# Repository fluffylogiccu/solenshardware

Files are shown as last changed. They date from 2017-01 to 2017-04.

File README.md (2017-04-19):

# solenshardware
_Most definitely not hardware_

----

For current schematics (not necessarily matching last board spin!), see [Solens_Schematic.pdf](https://github.com/fluffylogiccu/solenshardware/blob/master/Altium/Solens/Project%20Outputs%20for%20Solens/Solens_Schematic.pdf)

For the current state of the board (board layers, overview, schematic, etc), see [Solens_All.pdf](https://github.com/fluffylogiccu/solenshardware/blob/master/Altium/Solens/Project%20Outputs%20for%20Solens/Solens_All.pdf)

For schematics and board files matching a particular spin, see [Releases](https://github.com/fluffylogiccu/solenshardware/releases). Each release has up-to-date Gerbers corresponding to the board files, as well as the matching BOM.

A wiki (still under development) can be found [here](https://github.com/fluffylogiccu/solenshardware/wiki). The wiki is _not_ full documentation, due to the nature of Senior Design Lab, our team's design documents are not yet public. Eventually, we hope to open-source this project.

----

## Rev. B PCB

Rev. B top

Rev. B bottom

----

## Rev. A PCB

Rev. A top

Rev. A bottom

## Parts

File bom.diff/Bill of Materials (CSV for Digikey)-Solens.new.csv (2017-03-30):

DigikeyPN | Quantity | Designator | Value | PartNumber | Comment | Footprint | Description | LibRef | Library Reference | LoadCapacitance | Model:Footprint | Pins | ScrewSize | VisibleNetName
LTC2055HMS8#PBF-ND | 1 | U302 |  | LTC2055 |  | TSOP65P490X110-8N | Dual zero-drift op amp | LTC2054/LTC2055 | LTC2054/LTC2055 |  | TSOP, 8-Leads, Body 3.00x3.00mm (LTC2054/LTC2055) | 8
638-1120-1-ND | 1 | U301 |  | EMC1412-1-ACZL-TR |  | TSOP65P490X110-8N | Dual channel I2C temperature sensor | EMC1412 | EMC1412 |  | TSOP, 8-Leads, Body 3.00x3.00mm, Pitch 0.65mm (MSOP-8, MCP79412) | 8
MCP79412-I/MS-ND | 1 | U300 |  | MCP79412 |  | TSOP65P490X110-8N | I2C RTC w/ SRAM and EEPROM | MCP7941x | MCP7941x |  | TSOP, 8-Leads, Body 3.00x3.00mm, Pitch 0.65mm (MSOP-8, MCP79412) | 8
732-7046-1-ND | 3 | SW100, SW101, SW700 |  | 434121043816 | BTN0, RESET, RESET | 4341x10438x6 | WS-TASV 6.0x3.5 mm SMD | WS-TASV, 434121043816 | WS-TASV, 434121043816 |  | 6.0*3.5mm vertical type, SMD, height 4.3mm, white actuator, 260gf, T&R | 2
LTC2943IDD#PBF-ND | 1 | U203 |  | LTC2943 |  | DFN8-3x3 | Multi-cell I2C fuel gauge | LTC2943A | LTC2943A |  | LTC2943 | 9
497-1549-1-ND | 1 | U201 |  | LM234SM | LM234SM | SOIC127P600X175-8N (LM234) | Adjustable current source | LM234 | LM234 |  | SOIC, 8-Leads, Body 4.90x3.90mm, Pitch 1.27mm, | 3
36-5016CT-ND | 5 | TP105, TP106, TP200, TP303, TP702 |  |  | TP_LARGE | TP_LARGE |  | TP_LARGE | TP_LARGE |  | 5016 | 1 |  | GND
568-5818-1-ND | 2 | Q700, Q701 |  | 2N7002 |  | SOT95P240X100-3N (CMPSH1-4 TR) | N-Channel MOSFET | MOSFET-N | MOSFET-N |  | SOT23, 3-Leads, Body 2.90x2.40mm, | 3
MMBT3904LT1GOSCT-ND | 1 | Q300 |  | MMBT3904 |  | SOT90P240X110-3N | NPN General Purpose Amplifier | 2N3904 | 2N3904 |  | SOT23, 3-Leads, Body 2.90x2.40mm, Pitch 0.90mm, MMBT3904 | 3
36-9923-ND | 4 | MTGH1, MTGH2, MTGH3, MTGH4 |  |  | MTGH | MTGH-M3x0.5-ClipSW, MTGH-M3x0.5-ClipNW, MTGH-M3x0.5-ClipNE, MTGH-M3x0.5 | Mounting hole | MTGH | MTGH |  | M3 x 0.5 pan head mounting hole, SW corner clipped, M3 x 0.5 pan head mounting hole, NW corner clipped, M3 x 0.5 pan head mounting hole, NE corner clipped, M3 x 0.5 pan head mounting hole | 1 | M3x0.5
LT8608IMSE#PBF-ND | 1 | U400 |  | LT8608 |  | TSSOP50P490X110_HS-11N | 42V 1.5A step-down, low Iq | LT8608 | LT8608 |  | TSSOP, 10-Leads, Body 3.00x3.00mm, Pitch 0.50mm, Thermal Pad 1.88x1.68mm, IPC Medium Density | 11
609-3201-ND | 1 | JP700 |  |  | 2x2 100 mil | HDR2X2 | Header, 2-Pin, Dual row | Header 2X2 | Header 2X2 |  | Connector; Header; 2x2 Position | 4
732-5316-ND | 1 | JP200 |  |  | SHDN_EN | HDR_100TH_1x3 | 3-pos Jumper | JP-3 | JP-3 |  | 100TH pin header 1x3 vertical | 3
609-3264-ND | 1 | J700 |  |  | HDR_FTDI_EXTENDED | HDR1X8 |  | HDR_FTDI_EXTENDED | HDR_FTDI_EXTENDED |  | Connector; Header; 8 Position | 8
LT3652HVIMSE#PBF-ND | 1 | U200 |  | LT3652 |  | TSOP65P490X110_HS-13N (LT3652) | MPPC and battery charger | LT3652 | LT3652 |  | TSOP, 12-Leads, Body 4.04x3.00mm, Pitch 0.65mm, Thermal Pad 2.95x1.76mm, | 13
497-14053-ND | 1 | U100 |  | STM32F429 | STM32F429 | TSQFP50P2200X2200X160-144M | Cortex-M4 microcontroller | STM32F429 | STM32F429 |  | TSQFP, 144-Leads, Body 20.00x20.00mm, Pitch 0.50mm, STM32F429 | 144
609-3221-ND | 1 | J600 |  |  | CAMERA_2x10 | OV5642_HDR_2x10 | 20-pin parallel camera connector for OV5642 | CAMERA_2x10 | CAMERA_2x10 |  | OV5642 camera 100TH pin header 2x10 vertical | 20
732-5317-ND | 1 | J400 |  |  | EXT 3V3 | HDR1X4 | Header, 4-Pin | Header 4 | Header 4 |  | Connector; Header; 4 Position | 4
732-2772-ND | 1 | J200 |  | 691322110005 | 691322110005 | 691322110005 | WR-TBL Terminal block - serie 3221 - 3.50 mm | 691322110005 | 691322110005 |  | 3,50mm - PCB Horizontal - 05p | 5
36-5015CT-ND | 19 | TP100, TP101, TP104, TP203, TP204, TP205, TP207, TP208, TP209, TP300, TP301, TP302, TP304, TP305, TP306, TP600, TP601, TP700, TP701 |  |  |  | TP_SMALL |  | TP_SMALL | TP_SMALL |  | 5015 | 1 |  | TX, RX, 3V3, VBAT_INT, VINFB, VFB, VBAT, CHRG, FAULT, SDA, SCL, ALERT, SPECT0, SPECT1, LED0, SDA, SCL, TX, RX
WM17452-ND | 2 | J103, J701 |  |  | HDR_SWD_2x6, ESP_GPIO | HDR_100TH_2X6_SMT | 6 pin SWD connector with +6 GND pins, Header, 6-Pin, Dual row | HDR_SWD_2x6, Header 6X2 | HDR_SWD_2x6, Header 6X2 |  | 100TH pin header, 2x6, SMT | 12
WM17454-ND | 1 | J102 |  |  | GPIO | HDR_100TH_2X8_SMT | Header, 8-Pin, Dual row | Header 8X2 | Header 8X2 |  | 100TH pin header, 2x8, SMT | 16
 | 21 | J101, R106, R107, R108, R205, SJ100, SJ101, SJ102, SJ106, SJ107, SJ108, SJ109, SJ112, SJ200, SJ201, SJ300, SJ301, SJ700, TP500, TP501, U700 |  |  | 2x2 100 mil SMT, 0805, 0805, 0805, 0805, 0805, 0805, 0805, 0805, 0805, 0805, 0805, 0805, SJ, SJ, 0805, 0805, 1206, TP_TINY, TP_TINY, [NoValue] | HDR_100TH_2X2_SMT, RES_0805, RES_0805, RES_0805, RES_0805, SJ_0805, SJ_0805, SJ_0805, SJ_0805, SJ_0805, SJ_0805, SJ_0805, SJ_0805, SJ_0805, SJ_0805, SJ_0805, SJ_0805, SJ_1206, TP_TINY, TP_TINY, ESP8266 ESP-12-E | Header, 2-Pin, Dual row, Resistor, Resistor, Resistor, Resistor, Solder jumper, Solder jumper, Solder jumper, Solder jumper, Solder jumper, Solder jumper, Solder jumper, Solder jumper, Solder jumper, Solder jumper, Solder jumper, Solder jumper, Solder jumper, [NoValue], [NoValue], ESP8266 ESP-12-E | Header 2X2, Res1, Res1, Res1, Res1, SJ, SJ, SJ, SJ, SJ, SJ, SJ, SJ, SJ, SJ, SJ, SJ, SJ, TP_TINY, TP_TINY, ESP8266 ESP-12-E | Header 2X2, Res1, Res1, Res1, Res1, SJ, SJ, SJ, SJ, SJ, SJ, SJ, SJ, SJ, SJ, SJ, SJ, SJ, TP_TINY, TP_TINY, ESP8266 ESP-12-E |  | 100TH pin header, 2x2, SMT, [NoValue], [NoValue], [NoValue], [NoValue], [NoValue], [NoValue], [NoValue], [NoValue], [NoValue], [NoValue], [NoValue], [NoValue], [NoValue], [NoValue], [NoValue], [NoValue], A big fat solder jumper for high-current, 1mm round tiny testpoint, 1mm round tiny testpoint, ESP8266 ESP-12-E |  |  | [NoParam], [NoParam], [NoParam], [NoParam], [NoParam], [NoParam], [NoParam], [NoParam], [NoParam], [NoParam], [NoParam], [NoParam], [NoParam], [NoParam], [NoParam], [NoParam], [NoParam], [NoParam], GND, CLK, [NoParam]
609-3263-ND | 1 | J100 |  |  | HDR_FTDI | HDR_100TH_1x6 | Sparkfun FTDI pinout connector | HDR_FTDI | HDR_FTDI |  | 100TH pin header 1x6 vertical | 6
732-4978-1-ND | 3 | D301, D305, D400 |  |  | 0603, 0603, 3V3 | LED_0603 | Typical INFRARED GaAs LED, Typical INFRARED GaAs LED, [NoValue] | LED0 | LED0 |  |  | 2
732-4971-1-ND | 3 | D203, D204, D300 |  |  | CHRG, FAULT, 0603 | LED_0603 | [NoValue], [NoValue], Typical INFRARED GaAs LED | LED0 | LED0 |  |  | 2
CMPSH1-4 CT-ND | 1 | D202 |  | CMPSH1-4 |  | SOT95P240X100-3N (CMPSH1-4 TR) | Schottky Diode | D Schottky | D Schottky |  | SOT23, 3-Leads, Body 2.90x2.40mm, | 2
CMSH3-40MA TR13CT-ND | 2 | D200, D201 |  | CMSH3-40MA |  | SODFL519X262-2N (CMSH3-40MA) | Schottky Diode | D Schottky | D Schottky |  | SODFL, 2-Leads, Body 2.60x5.19mm, | 2
706-1132-ND | 1 | U500 |  | IS42S16400J |  | TSOP80P1170X120-54N | 1Mb x 16 x 4 bank (64 Mbit) SDRAM | IS42S16400J | IS42S16400J |  | TSOP, 54-Leads, Body 22.22x10.16mm, (IS42S16400J) | 54
36-5106CT-ND | 1 | R400 | 0 |  | 1206 | RES_1206 | Resistor | Res1 | Res1 |  |  | 2
311-1.00MLRCT-ND | 2 | R303, R308 | 1M |  | 0402 | RES_0402 | Resistor | Res1 | Res1 |  |  | 2
311-1.00MCRCT-ND | 1 | R401 | 1M |  | 0805 | RES_0805 | Resistor | Res1 | Res1 |  |  | 2
311-1.00KCRCT-ND | 1 | R208 | 1k |  | 0805 | RES_0805 | Resistor | Res1 | Res1 |  |  | 2
1276-1020-1-ND | 1 | C700 | 1n |  | 0805 | CAP_0805 | Capacitor | Cap | Cap |  |  | 2
1276-6470-1-ND | 2 | C200, C207 | 1u |  | 0805,50V, 0805 | CAP_0805 | Capacitor | Cap | Cap |  |  | 2
587-2098-1-ND | 1 | L400 | 2.2u | NR6028T2R2N |  | IND_TAIYO_NR6028 | Inductor | Inductor | Inductor |  |  | 2
1276-6458-1-ND | 4 | C113, C114, C115, C407 | 2.2u |  | 0805 | CAP_0805 | Capacitor | Cap | Cap |  |  | 2
311-3.30KCRCT-ND | 5 | R300, R301, R302, R600, R601 | 3.3k |  | 0805 | RES_0805 | Resistor | Res1 | Res1 |  |  | 2
1276-3343-1-ND | 3 | C201, C202, C203 | 4.7u |  | 1210,50V | CAP_1210 | Capacitor | Cap | Cap |  |  | 2
887-1263-1-ND | 1 | Y100 | 8M000 | 9C-8.000MEEJ-T |  | HC-49S | Crystal Oscillator | XTAL | XTAL | 18p | Crystal | 2
311-10.0KCRCT-ND | 7 | R700, R701, R702, R703, R706, R708, R711 | 10k |  | 0805 | RES_0805 | Resistor | Res1 | Res1 |  |  | 2
3361P-103GLFCT-ND | 1 | VR200 | 10k |  | Vin Set | RES_3361P |  | TrimPot | TrimPot |  | POT | 3
1276-1015-1-ND | 1 | C408 | 10n |  | 0805 | CAP_0805 | Capacitor | Cap | Cap |  |  | 2
1276-1109-1-ND | 1 | C403 | 10p |  | 0805 | CAP_0805 | Capacitor | Cap | Cap |  |  | 2
1276-6455-1-ND | 2 | C404, C406 | 10u |  | 0805 | CAP_0805 | Capacitor | Cap | Cap |  |  | 2
1276-1312-1-ND | 5 | C205, C206, C401, C601, C702 | 10u |  | 1206,16V, 1206,16V, 1206,16V, 1206,16V, 1206 | CAP_1206 | Capacitor | Cap | Cap |  |  | 2
587-2973-1-ND | 1 | L200 | 15u | NRS8040T150MJGJ |  | IND_TAIYO_NRS804 | Inductor | Inductor | Inductor |  |  | 2
490-6203-1-ND | 4 | C102, C103, C300, C301 | 18p |  | 0402 | CAP_0402 | Capacitor | Cap | Cap |  |  | 2
311-20.5KCRCT-ND | 1 | R405 | 20.5k |  | 0805 | RES_0805 | Resistor | Res1 | Res1 |  |  | 2
311-22.0KCRCT-ND | 4 | R201, R202, R204, R206 | 22k |  | 0805 | RES_0805 | Resistor | Res1 | Res1 |  |  | 2
CSR1206FK25L0CT-ND | 1 | R210 | 25m |  | 1206 | RES_1206 | Resistor | Res1 | Res1 |  |  | 2
1276-1153-1-ND | 2 | C100, C101 | 27p |  | 0402 | CAP_0402 | Capacitor | Cap | Cap |  |  | 2
535-9166-1-ND | 2 | Y101, Y300 | 32K768 | ABS25-32.768KHZ-T |  | XTAL-SOJ-4 |  | XTAL-SOJ-4 | XTAL-SOJ-4 | 12.5p |  | 4
CRA6S833CT-ND | 7 | RR503, RR504, RR505, RR506, RR600, RR601, RR602 | 33 |  | RES_ARR_4 | CAC-80P319X150-8M | 4 element resistor array | RES_ARR_4 | RES_ARR_4 |  | Chip Array, ConvexS, 8-Leads, Pitch 0.80mm, Body 3.20x1.50mm, for Vishay CRA06S | 8
1276-3063-1-ND | 3 | C405, C600, C701 | 47u |  | 1206,10V | CAP_1206 | Capacitor | Cap | Cap |  |  | 2
CRA6S849.9ACT-ND | 5 | RR500, RR501, RR502, RR507, RR508 | 49.9 |  | RES_ARR_4 | CAC-80P319X150-8M | 4 element resistor array | RES_ARR_4 | RES_ARR_4 |  | Chip Array, ConvexS, 8-Leads, Pitch 0.80mm, Body 3.20x1.50mm, for Vishay CRA06S | 8
311-49.9CRCT-ND | 5 | R110, R500, R501, R502, R602 | 49.9 |  | 0805 | RES_0805 | Resistor | Res1 | Res1 |  |  | 2
WSLC-.08CT-ND | 1 | R200 | 80m |  | 1206 | RES_1206 | Resistor | Res1 | Res1 |  |  | 2
311-100CRCT-ND | 10 | R101, R102, R104, R105, R704, R705, R707, R709, R710, R712 | 100 |  | 0805 | RES_0805 | Resistor | Res1 | Res1 |  |  | 2
311-100KCRCT-ND | 1 | R402 | 100k |  | 0805 | RES_0805 | Resistor | Res1 | Res1 |  |  | 2
587-3498-1-ND | 30 | C104, C105, C106, C107, C108, C109, C110, C111, C112, C116, C117, C118, C119, C120, C121, C122, C124, C204, C302, C303, C400, C402, C500, C501, C502, C503, C504, C505, C506, C507 | 100n |  | 0402 | CAP_0402 | Capacitor | Cap | Cap |  |  | 2
311-0.0ARCT-ND | 1 | R103 | 220 |  | 0805 | RES_0805 | Resistor | Res1 | Res1 |  |  | 2
490-1293-1-ND | 2 | C304, C305 | 220p |  | 0402 | CAP_0402 | Capacitor | Cap | Cap |  |  | 2
311-309KCRCT-ND | 1 | R404 | 309k |  | 0805 | RES_0805 | Resistor | Res1 | Res1 |  |  | 2
311-330CRCT-ND | 2 | R304, R406 | 330 |  | 0805 | RES_0805 | Resistor | Res1 | Res1 |  |  | 2
311-487KCRCT-ND | 1 | R207 | 487k |  | 0805 | RES_0805 | Resistor | Res1 | Res1 |  |  | 2
311-510CRCT-ND | 1 | R109 | 510 |  | 0805 | RES_0805 | Resistor | Res1 | Res1 |  |  | 2
311-511KCRCT-ND | 1 | R203 | 511k |  | 0805 | RES_0805 | Resistor | Res1 | Res1 |  |  | 2

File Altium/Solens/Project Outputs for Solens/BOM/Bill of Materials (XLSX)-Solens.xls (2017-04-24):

Item # | Designator | Value | Footprint | Comment | LibRef | Quantity | #Column Name Error:PackageName | PartNumber | #Column Name Error:PartType | Pins | Model:Footprint
1 | R106 | 0R | RES_0805 | 0R, 1/8W, 0805 (DNP) | Res1 | 1 |  |  |  | 2
2 | R400 | 0R 1/2W | RES_1206 | 0R, 1/2W, 1206 | Res1 | 1 |  |  |  | 2
3 | R208 | 1k | RES_0805 | 1k, 1/8W, 0805 | Res1 | 1 |  |  |  | 2
4 | R303 | 1M | RES_0402 | 1M, 1/16W, 0402 (DNP) | Res1 | 1 |  |  |  | 2
5 | R308 | 1M | RES_0402 | 1M, 1/16W, 0402 (DNP) | Res1 | 1 |  |  |  | 2
6 | R401 | 1M | RES_0805 | 1M, 1/8W, 0805 | Res1 | 1 |  |  |  | 2
7 | C700 | 1n, 10V | CAP_0805 | 1n, 16V, 0805 | Cap | 1 |  |  |  | 2
8 | C200 | 1u, 35V | CAP_0805 | 1u, 35V, 0805 | Cap | 1 |  |  |  | 2
9 | C207 | 1u, 35V | CAP_0805 | 1u, 35V, 0805 (DNP) | Cap | 1 |  |  |  | 2
10 | R205 | 2k4 | RES_0805 | 2k4, 1/8W, 0805 (DNP) | Res1 | 1 |  |  |  | 2
11 | Q700 | 2N7002 | SOT95P240X100-3N (CMPSH1-4 TR) | 2N7002, SOT-23 | MOSFET-N | 1 |  | 2N7002 |  | 3 | SOT23, 3-Leads, Body 2.90x2.40mm,
12 | Q701 | 2N7002 | SOT95P240X100-3N (CMPSH1-4 TR) | 2N7002, SOT-23 | MOSFET-N | 1 |  | 2N7002 |  | 3 | SOT23, 3-Leads, Body 2.90x2.40mm,
13 | C113 | 2u2, 10V | CAP_0805 | 2u2, 10V, 0805 | Cap | 1 |  |  |  | 2
14 | C114 | 2u2, 10V | CAP_0805 | 2u2, 10V, 0805 | Cap | 1 |  |  |  | 2
15 | C115 | 2u2, 10V | CAP_0805 | 2u2, 10V, 0805 | Cap | 1 |  |  |  | 2
16 | C407 | 2u2, 10V | CAP_0805 | 2u2, 10V, 0805 | Cap | 1 |  |  |  | 2
17 | L400 | 2.2u | IND_TAIYO_NR6028 | NR6028T2R2N | Inductor | 1 |  | NR6028T2R2N |  | 2
18 | R300 | 3k3 | RES_0805 | 3k3, 1/8W, 0805 (DNP) | Res1 | 1 |  |  |  | 2
19 | R301 | 3k3 | RES_0805 | 3k3, 1/8W, 0805 (DNP) | Res1 | 1 |  |  |  | 2
20 | R302 | 3k3 | RES_0805 | 3k3, 1/8W, 0805 (DNP) | Res1 | 1 |  |  |  | 2
21 | R600 | 3k3 | RES_0805 | 3k3, 1/8W, 0805 | Res1 | 1 |  |  |  | 2
22 | R601 | 3k3 | RES_0805 | 3k3, 1/8W, 0805 | Res1 | 1 |  |  |  | 2
23 | C201 | 4u7, 50V | CAP_1210 | 4u7, 50V, 1210 | Cap | 1 |  |  |  | 2
24 | C202 | 4u7, 50V | CAP_1210 | 4u7, 50V, 1210 | Cap | 1 |  |  |  | 2
25 | C203 | 4u7, 50V | CAP_1210 | 4u7, 50V, 1210 | Cap | 1 |  |  |  | 2
26 | Y100 | 8M000 | HC-49S | 9C-8.000MEEJ-T | XTAL | 1 |  | 9C-8.000MEEJ-T |  | 2 | Crystal
27 | R700 | 10k | RES_0805 | 10k, 1/8W, 0805 | Res1 | 1 |  |  |  | 2
28 | R701 | 10k | RES_0805 | 10k, 1/8W, 0805 | Res1 | 1 |  |  |  | 2
29 | R702 | 10k | RES_0805 | 10k, 1/8W, 0805 | Res1 | 1 |  |  |  | 2
30 | R703 | 10k | RES_0805 | 10k, 1/8W, 0805 | Res1 | 1 |  |  |  | 2
31 | R706 | 10k | RES_0805 | 10k, 1/8W, 0805 | Res1 | 1 |  |  |  | 2
32 | R708 | 10k | RES_0805 | 10k, 1/8W, 0805 | Res1 | 1 |  |  |  | 2
33 | R711 | 10k | RES_0805 | 10k, 1/8W, 0805 | Res1 | 1 |  |  |  | 2
34 | VR200 | 10k LIN | RES_3361P | 3361P-1-103GLF | TrimPot | 1 |  | 3361P-1-103GLF |  | 3 | POT
35 | C408 | 10n, 16V | CAP_0805 | 10n, 16V, 0805 | Cap | 1 |  |  |  | 2
36 | C403 | 10p, 16V | CAP_0805 | 10p, 16V, 0805 | Cap | 1 |  |  |  | 2
37 | C404 | 10u, 10V | CAP_0805 | 10u, 10V, 0805 | Cap | 1 |  |  |  | 2
38 | C406 | 10u, 10V | CAP_0805 | 10u, 10V, 0805 | Cap | 1 |  |  |  | 2
39 | C601 | 10u, 10V | CAP_1206 | 10u, 10V, 1206 | Cap | 1 |  |  |  | 2
40 | C702 | 10u, 10V | CAP_1206 | 10u, 10V, 1206 | Cap | 1 |  |  |  | 2
41 | C205 | 10u, 16V | CAP_1206 | 10u, 16V, 1206 | Cap | 1 |  |  |  | 2
42 | C206 | 10u, 16V | CAP_1206 | 10u, 16V, 1206 | Cap | 1 |  |  |  | 2
43 | C401 | 10u, 16V | CAP_1206 | 10u, 16V, 1206 | Cap | 1 |  |  |  | 2
44 | L200 | 15u | IND_TAIYO_NRS804 | NRS8040T150MJGJ | Inductor | 1 |  | NRS8040T150MJGJ |  | 2
45 | C102 | 18p, 16V | CAP_0402 | 18p, 16V, 0402 | Cap | 1 |  |  |  | 2
46 | C103 | 18p, 16V | CAP_0402 | 18p, 16V, 0402 | Cap | 1 |  |  |  | 2
47 | C300 | 18p, 16V | CAP_0402 | 18p, 16V, 0402 (DNP) | Cap | 1 |  |  |  | 2
48 | C301 | 18p, 16V | CAP_0402 | 18p, 16V, 0402 (DNP) | Cap | 1 |  |  |  | 2
49 | R405 | 20k5 | RES_0805 | 20k5, 1/8W, 0805 | Res1 | 1 |  |  |  | 2
50 | R201 | 22k | RES_0805 | 22k, 1/8W, 0805 | Res1 | 1 |  |  |  | 2
51 | R202 | 22k | RES_0805 | 22k, 1/8W, 0805 | Res1 | 1 |  |  |  | 2
52 | R204 | 22k | RES_0805 | 22k, 1/8W, 0805 | Res1 | 1 |  |  |  | 2
53 | R206 | 22k | RES_0805 | 22k, 1/8W, 0805 | Res1 | 1 |  |  |  | 2
54 | R210 | 25m, 1%, 1/2W | RES_1206 | 25m, 1/2W, 1%, 1206 | Res1 | 1 |  |  |  | 2
55 | C100 | 27p, 16V | CAP_0402 | 27p, 16V, 0402 | Cap | 1 |  |  |  | 2
56 | C101 | 27p, 16V | CAP_0402 | 27p, 16V, 0402 | Cap | 1 |  |  |  | 2
57 | Y101 | 32k768 | XTAL-SOJ-4 | ABS25-32.768KHZ-T | XTAL-SOJ-4 | 1 |  | ABS25-32.768KHZ-T |  | 4
58 | Y300 | 32k768 | XTAL-SOJ-4 | ABS25-32.768KHZ-T (DNP) | XTAL-SOJ-4 | 1 |  | ABS25-32.768KHZ-T |  | 4
59 | RR503 | 33R | CAC-80P319X150-8M | CRA6S833CT-ND | RES_ARR_4 | 1 |  |  |  | 8 | Chip Array, ConvexS, 8-Leads, Pitch 0.80mm, Body 3.20x1.50mm, for Vishay CRA06S
60 | RR504 | 33R | CAC-80P319X150-8M | CRA6S833CT-ND | RES_ARR_4 | 1 |  |  |  | 8 | Chip Array, ConvexS, 8-Leads, Pitch 0.80mm, Body 3.20x1.50mm, for Vishay CRA06S
61 | RR505 | 33R | CAC-80P319X150-8M | CRA6S833CT-ND | RES_ARR_4 | 1 |  |  |  | 8 | Chip Array, ConvexS, 8-Leads, Pitch 0.80mm, Body 3.20x1.50mm, for Vishay CRA06S
62 | RR506 | 33R | CAC-80P319X150-8M | CRA6S833CT-ND | RES_ARR_4 | 1 |  |  |  | 8 | Chip Array, ConvexS, 8-Leads, Pitch 0.80mm, Body 3.20x1.50mm, for Vishay CRA06S
63 | RR600 | 33R | CAC-80P319X150-8M | CRA6S833CT-ND | RES_ARR_4 | 1 |  |  |  | 8 | Chip Array, ConvexS, 8-Leads, Pitch 0.80mm, Body 3.20x1.50mm, for Vishay CRA06S
64 | RR601 | 33R | CAC-80P319X150-8M | CRA6S833CT-ND | RES_ARR_4 | 1 |  |  |  | 8 | Chip Array, ConvexS, 8-Leads, Pitch 0.80mm, Body 3.20x1.50mm, for Vishay CRA06S
65 | RR602 | 33R | CAC-80P319X150-8M | CRA6S833CT-ND | RES_ARR_4 | 1 |  |  |  | 8 | Chip Array, ConvexS, 8-Leads, Pitch 0.80mm, Body 3.20x1.50mm, for Vishay CRA06S
66 | C405 | 47u, 10V | CAP_1206 | 47u, 10V, 1206 | Cap | 1 |  |  |  | 2
67 | C600 | 47u, 10V | CAP_1206 | 47u, 10V, 1206 | Cap | 1 |  |  |  | 2
68 | C701 | 47u, 10V | CAP_1206 | 47u, 10V, 1206 | Cap | 1 |  |  |  | 2
69 | R110 | 49R9 | RES_0805 | 49R9, 1/8W, 0805 (DNP) | Res1 | 1 |  |  |  | 2
70 | R500 | 49R9 | RES_0805 | 49R9, 1/8W, 0805 | Res1 | 1 |  |  |  | 2
71 | R501 | 49R9 | RES_0805 | 49R9, 1/8W, 0805 | Res1 | 1 |  |  |  | 2
72 | R502 | 49R9 | RES_0805 | 49R9, 1/8W, 0805 | Res1 | 1 |  |  |  | 2
73 | R602 | 49R9 | RES_0805 | 49R9, 1/8W, 0805 | Res1 | 1 |  |  |  | 2
74 | RR500 | 49R9 | CAC-80P319X150-8M | CRA6S849.9ACT-ND | RES_ARR_4 | 1 |  |  |  | 8 | Chip Array, ConvexS, 8-Leads, Pitch 0.80mm, Body 3.20x1.50mm, for Vishay CRA06S
75 | RR501 | 49R9 | CAC-80P319X150-8M | CRA6S849.9ACT-ND | RES_ARR_4 | 1 |  |  |  | 8 | Chip Array, ConvexS, 8-Leads, Pitch 0.80mm, Body 3.20x1.50mm, for Vishay CRA06S
76 | RR502 | 49R9 | CAC-80P319X150-8M | CRA6S849.9ACT-ND | RES_ARR_4 | 1 |  |  |  | 8 | Chip Array, ConvexS, 8-Leads, Pitch 0.80mm, Body 3.20x1.50mm, for Vishay CRA06S
77 | RR507 | 49R9 | CAC-80P319X150-8M | CRA6S849.9ACT-ND | RES_ARR_4 | 1 |  |  |  | 8 | Chip Array, ConvexS, 8-Leads, Pitch 0.80mm, Body 3.20x1.50mm, for Vishay CRA06S
78 | RR508 | 49R9 | CAC-80P319X150-8M | CRA6S849.9ACT-ND | RES_ARR_4 | 1 |  |  |  | 8 | Chip Array, ConvexS, 8-Leads, Pitch 0.80mm, Body 3.20x1.50mm, for Vishay CRA06S
79 | R200 | 80m | RES_1206 | 80m, 1/4W, 1%, 1206 | Res1 | 1 |  |  |  | 2
80 | R402 | 100k | RES_0805 | 100k, 1/8W, 0805 | Res1 | 1 |  |  |  | 2
81 | C104 | 100n, 16V | CAP_0402 | 100n, 16V, 0402 | Cap | 1 |  |  |  | 2
82 | C105 | 100n, 16V | CAP_0402 | 100n, 16V, 0402 | Cap | 1 |  |  |  | 2
83 | C106 | 100n, 16V | CAP_0402 | 100n, 16V, 0402 | Cap | 1 |  |  |  | 2
84 | C107 | 100n, 16V | CAP_0402 | 100n, 16V, 0402 | Cap | 1 |  |  |  | 2
85 | C108 | 100n, 16V | CAP_0402 | 100n, 16V, 0402 | Cap | 1 |  |  |  | 2
86 | C109 | 100n, 16V | CAP_0402 | 100n, 16V, 0402 | Cap | 1 |  |  |  | 2
87 | C110 | 100n, 16V | CAP_0402 | 100n, 16V, 0402 | Cap | 1 |  |  |  | 2
88 | C111 | 100n, 16V | CAP_0402 | 100n, 16V, 0402 | Cap | 1 |  |  |  | 2
89 | C112 | 100n, 16V | CAP_0402 | 100n, 16V, 0402 | Cap | 1 |  |  |  | 2
90 | C116 | 100n, 16V | CAP_0402 | 100n, 16V, 0402 | Cap | 1 |  |  |  | 2
91 | C117 | 100n, 16V | CAP_0402 | 100n, 16V, 0402 | Cap | 1 |  |  |  | 2
92 | C118 | 100n, 16V | CAP_0402 | 100n, 16V, 0402 | Cap | 1 |  |  |  | 2
93 | C119 | 100n, 16V | CAP_0402 | 100n, 16V, 0402 | Cap | 1 |  |  |  | 2
94 | C120 | 100n, 16V | CAP_0402 | 100n, 16V, 0402 | Cap | 1 |  |  |  | 2
95 | C121 | 100n, 16V | CAP_0402 | 100n, 16V, 0402 | Cap | 1 |  |  |  | 2
96 | C122 | 100n, 16V | CAP_0402 | 100n, 16V, 0402 | Cap | 1 |  |  |  | 2
97 | C124 | 100n, 16V | CAP_0402 | 100n, 16V, 0402 | Cap | 1 |  |  |  | 2
98 | C204 | 100n, 16V | CAP_0402 | 100n, 16V, 0402 | Cap | 1 |  |  |  | 2
99 | C302 | 100n, 16V | CAP_0402 | 100n, 16V, 0402 (DNP) | Cap | 1 |  |  |  | 2
100 | C303 | 100n, 16V | CAP_0402 | 100n, 16V, 0402 (DNP) | Cap | 1 |  |  |  | 2
101 | C400 | 100n, 16V | CAP_0402 | 100n, 16V, 0402 | Cap | 1 |  |  |  | 2
102 | C402 | 100n, 16V | CAP_0402 | 100n, 16V, 0402 | Cap | 1 |  |  |  | 2
103 | C500 | 100n, 16V | CAP_0402 | 100n, 16V, 0402 | Cap | 1 |  |  |  | 2
104 | C501 | 100n, 16V | CAP_0402 | 100n, 16V, 0402 | Cap | 1 |  |  |  | 2
105 | C502 | 100n, 16V | CAP_0402 | 100n, 16V, 0402 | Cap | 1 |  |  |  | 2
106 | C503 | 100n, 16V | CAP_0402 | 100n, 16V, 0402 | Cap | 1 |  |  |  | 2
107 | C504 | 100n, 16V | CAP_0402 | 100n, 16V, 0402 | Cap | 1 |  |  |  | 2
108 | C505 | 100n, 16V | CAP_0402 | 100n, 16V, 0402 | Cap | 1 |  |  |  | 2
109 | C506 | 100n, 16V | CAP_0402 | 100n, 16V, 0402 | Cap | 1 |  |  |  | 2
110 | C507 | 100n, 16V | CAP_0402 | 100n, 16V, 0402 | Cap | 1 |  |  |  | 2
111 | R101 | 100R | RES_0805 | 100R, 1/8W, 0805 | Res1 | 1 |  |  |  | 2
112 | R102 | 100R | RES_0805 | 100R, 1/8W, 0805 | Res1 | 1 |  |  |  | 2
113 | R104 | 100R | RES_0805 | 100R, 1/8W, 0805 (DNP) | Res1 | 1 |  |  |  | 2
114 | R105 | 100R | RES_0805 | 100R, 1/8W, 0805 (DNP) | Res1 | 1 |  |  |  | 2
115 | R704 | 100R | RES_0805 | 100R, 1/8W, 0805 | Res1 | 1 |  |  |  | 2
116 | R705 | 100R | RES_0805 | 100R, 1/8W, 0805 | Res1 | 1 |  |  |  | 2
117 | R707 | 100R | RES_0805 | 100R, 1/8W, 0805 | Res1 | 1 |  |  |  | 2
118 | R709 | 100R | RES_0805 | 100R, 1/8W, 0805 | Res1 | 1 |  |  |  | 2
119 | R710 | 100R | RES_0805 | 100R, 1/8W, 0805 (DNP) | Res1 | 1 |  |  |  | 2
120 | R712 | 100R | RES_0805 | 100R, 1/8W, 0805 (DNP) | Res1 | 1 |  |  |  | 2
121 | C304 | 220p, 10V | CAP_0402 | 220p, 16V, 0402 (DNP) | Cap | 1 |  |  |  | 2
122 | C305 | 220p, 10V | CAP_0402 | 220p, 16V, 0402 (DNP) | Cap | 1 |  |  |  | 2
123 | R103 | 220R | RES_0805 | 220R, 1/8W, 0805 | Res1 | 1 |  |  |  | 2
124 | R404 | 309k | RES_0805 | 309k, 1/8W, 0805 | Res1 | 1 |  |  |  | 2
125 | R304 | 330 | RES_0805 | 330, 1/8W, 0805 (DNP) | Res1 | 1 |  |  |  | 2
126 | R406 | 330R | RES_0805 | 330, 1/8W, 0805 | Res1 | 1 |  |  |  | 2
127 | R207 | 487k | RES_0805 | 487k, 1/8W, 0805 | Res1 | 1 |  |  |  | 2
128 | R109 | 510R | RES_0805 | 510R, 1/8W, 0805 | Res1 | 1 |  |  |  | 2
129 | R203 | 511k | RES_0805 | 511k, 1/8W, 0805 | Res1 | 1 |  |  |  | 2
130 | SW100 | 434121043816 | 4341x10438x6 | 434121043816, TACT SPST NO | WS-TASV, 434121043816 | 1 |  | 434121043816 |  | 2 | 6.0*3.5mm vertical type, SMD, height 4.3mm, white actuator, 260gf, T&R
131 | SW101 | 434121043816 | 4341x10438x6 | 434121043816, TACT SPST NO | WS-TASV, 434121043816 | 1 |  | 434121043816 |  | 2 | 6.0*3.5mm vertical type, SMD, height 4.3mm, white actuator, 260gf, T&R
132 | SW700 | 434121043816 | 4341x10438x6 | 434121043816, TACT SPST NO | WS-TASV, 434121043816 | 1 |  | 434121043816 |  | 2 | 6.0*3.5mm vertical type, SMD, height 4.3mm, white actuator, 260gf, T&R
133 | J200 | 691322110005 | 691322110005 | 691322110005, 5p 3.5mm Euro | 691322110005 | 1 |  | 691322110005 |  | 5 | 3,50mm - PCB Horizontal - 05p
134 | D202 | CMPSH1-4 | SOT95P240X100-3N (CMPSH1-4 TR) | CMPSH1-4, SOT-23F | D Schottky | 1 |  | CMPSH1-4 |  | 2 | SOT23, 3-Leads, Body 2.90x2.40mm,
135 | D200 | CMSH3-40MA | SODFL519X262-2N (CMSH3-40MA) | CMSH3-40MA, DO-214AC | D Schottky | 1 |  | CMSH3-40MA |  | 2 | SODFL, 2-Leads, Body 2.60x5.19mm,
136 | D201 | CMSH3-40MA | SODFL519X262-2N (CMSH3-40MA) | CMSH3-40MA, DO-214AC | D Schottky | 1 |  | CMSH3-40MA |  | 2 | SODFL, 2-Leads, Body 2.60x5.19mm,
137 | U301 | EMC1412 | TSOP65P490X110-8N | EMC1412, MSOP-8 (DNP) | EMC1412 | 1 |  | EMC1412-1-ACZL-TR |  | 8 | TSOP, 8-Leads, Body 3.00x3.00mm, Pitch 0.65mm (MSOP-8, MCP79412)
138 | U700 | ESP8266-12E | ESP8266 ESP-12-E | ESP8266-12E (DNP) | ESP8266 ESP-12-E | 1 |  | ESP8266-12E |  | 22 | ESP8266 ESP-12-E
139 | JP200 | HDR_1x3_100TH_THT | HDR_100TH_1x3 | HDR_1x3_100TH_THT | JP-3 | 1 |  |  |  | 3 | 100TH pin header 1x3 vertical
140 | J400 | HDR_1x4_100TH_THT | HDR1X4 | HDR_1x4_100TH_THT (DNP) | Header 4 | 1 |  |  |  | 4 | Connector; Header; 4 Position
141 | J100 | HDR_1x6_100TH_THT | HDR_100TH_1x6 | HDR_1x6_100TH_THT | HDR_FTDI | 1 |  |  |  | 6 | 100TH pin header 1x6 vertical
142 | J700 | HDR_1x8_100TH_THT | HDR1X8 | HDR_1x8_100TH_THT | HDR_FTDI_EXTENDED | 1 |  |  |  | 8 | Connector; Header; 8 Position
143 | J101 | HDR_2x2_100TH_SMT | HDR_100TH_2X2_SMT | HDR_2x2_100TH_SMT (DNP) | Header 2X2 | 1 |  |  |  | 4 | 100TH pin header, 2x2, SMT
144 | JP700 | HDR_2x2_100TH_THT | HDR2X2 | HDR_2x2_100TH_THT | Header 2X2 | 1 |  |  |  | 4 | Connector; Header; 2x2 Position
145 | J701 | HDR_2x6_100TH_SMT | HDR_100TH_2X6_SMT | HDR_2x6_100TH_SMT (DNP) | Header 6X2 | 1 |  |  |  | 12 | 100TH pin header, 2x6, SMT
146 | J102 | HDR_2x8_100TH_SMT | HDR_100TH_2X8_SMT | HDR_2x8_100TH_SMT (DNP) | Header 8X2 | 1 |  |  |  | 16 | 100TH pin header, 2x8, SMT
147 | J103 | HDR_2x8_100TH_SMT | HDR_100TH_2X6_SMT | HDR_2x8_100TH_SMT | HDR_SWD_2x6 | 1 |  |  |  | 12 | 100TH pin header, 2x6, SMT
148 | U500 | IS42S16400J | TSOP80P1170X120-54N | IS42S16400J, TSOP-54 | IS42S16400J | 1 |  | IS42S16400J |  | 54 | TSOP, 54-Leads, Body 22.22x10.16mm, (IS42S16400J)
149 | D203 | LED, GRN | LED_0603 | LED, GRN, 0603 (DNP) | LED0 | 1 |  |  |  | 2
150 | D204 | LED, GRN | LED_0603 | LED, GRN, 0603 (DNP) | LED0 | 1 |  |  |  | 2
151 | D300 | LED, GRN | LED_0603 | LED, GRN, 0603 (DNP) | LED0 | 1 |  |  |  | 2
152 | D301 | LED, RED | LED_0603 | LED, RED, 0603 (DNP) | LED0 | 1 |  |  |  | 2
153 | D305 | LED, RED | LED_0603 | LED, RED, 0603 (DNP) | LED0 | 1 |  |  |  | 2
154 | D400 | LED, RED | LED_0603 | LED, RED, 0603 (DNP) | LED0 | 1 |  |  |  | 2
155 | U201 | LM234SM | SOIC127P600X175-8N (LM234) | LM234SM, SOIC-8 (DNP) | LM234 | 1 |  | LM234SM |  | 3 | SOIC, 8-Leads, Body 4.90x3.90mm, Pitch 1.27mm,
156 | U200 | LT3652 | TSOP65P490X110_HS-13N (LT3652) | LT3652, MSOP-12 | LT3652 | 1 |  | LT3652 |  | 13 | TSOP, 12-Leads, Body 4.04x3.00mm, Pitch 0.65mm, Thermal Pad 2.95x1.76mm,
157 | U400 | LT8608 | TSSOP50P490X110_HS-11N | LT8608, MSOP-10 | LT8608 | 1 |  | LT8608 |  | 11 | TSSOP, 10-Leads, Body 3.00x3.00mm, Pitch 0.50mm, Thermal Pad 1.88x1.68mm, IPC Medium Density
158 | U302 | LTC2055 | TSOP65P490X110-8N | LTC2055, MSOP-8 (DNP) | LTC2054/LTC2055 | 1 |  | LTC2055 |  | 8 | TSOP, 8-Leads, Body 3.00x3.00mm (LTC2054/LTC2055)
159 | U203 | LTC2943 | DFN8-3x3 | LTC2943, DFN-8 | LTC2943A | 1 |  | LTC2943 |  | 9 | LTC2943
160 | MTGH1 | M3x0.5 (DNP) | MTGH-M3x0.5-ClipSW | M3x0.5 (DNP) | MTGH | 1 |  |  |  | 1 | M3 x 0.5 pan head mounting hole, SW corner clipped
161 | MTGH2 | M3x0.5 (DNP) | MTGH-M3x0.5-ClipNW | M3x0.5 (DNP) | MTGH | 1 |  |  |  | 1 | M3 x 0.5 pan head mounting hole, NW corner clipped
162 | MTGH3 | M3x0.5 (DNP) | MTGH-M3x0.5-ClipNE | M3x0.5 (DNP) | MTGH | 1 |  |  |  | 1 | M3 x 0.5 pan head mounting hole, NE corner clipped
163 | MTGH4 | M3x0.5 (DNP) | MTGH-M3x0.5 | M3x0.5 (DNP) | MTGH | 1 |  |  |  | 1 | M3 x 0.5 pan head mounting hole
164 | U300 | MCP79412 | TSOP65P490X110-8N | MCP79412, MSOP-8 (DNP) | MCP7941x | 1 |  | MCP79412 |  | 8 | TSOP, 8-Leads, Body 3.00x3.00mm, Pitch 0.65mm (MSOP-8, MCP79412)
165 | Q300 | MMBT3904 | SOT90P240X110-3N | MMBT3904, SOT-23 (DNP) | 2N3904 | 1 |  | MMBT3904 |  | 3 | SOT23, 3-Leads, Body 2.90x2.40mm, Pitch 0.90mm, MMBT3904
166 | R107 | Optional | RES_0805 | 0R, 1/8W, 0805 (DNP) | Res1 | 1 |  |  |  | 2
167 | R108 | Optional | RES_0805 | 0805 (DNP) | Res1 | 1 |  |  |  | 2
168 | SJ100 | SJ_0805 (DNP) | SJ_0805 | SJ, 0805 (DNP) | SJ | 1 |  |  |  | 2
169 | SJ101 | SJ_0805 (DNP) | SJ_0805 | SJ, 0805 (DNP) | SJ | 1 |  |  |  | 2
170 | SJ102 | SJ_0805 (DNP) | SJ_0805 | SJ, 0805 (DNP) | SJ | 1 |  |  |  | 2
171 | SJ106 | SJ_0805 (DNP) | SJ_0805 | SJ, 0805 (DNP) | SJ | 1 |  |  |  | 2
172 | SJ107 | SJ_0805 (DNP) | SJ_0805 | SJ, 0805 (DNP) | SJ | 1 |  |  |  | 2
173 | SJ108 | SJ_0805 (DNP) | SJ_0805 | SJ, 0805 (DNP) | SJ | 1 |  |  |  | 2
174 | SJ109 | SJ_0805 (DNP) | SJ_0805 | SJ, 0805 (DNP) | SJ | 1 |  |  |  | 2
175 | SJ112 | SJ_0805 (DNP) | SJ_0805 | SJ, 0805 (DNP) | SJ | 1 |  |  |  | 2
176 | SJ200 | SJ_0805 (DNP) | SJ_0805 | SJ, 0805 (DNP) | SJ | 1 |  |  |  | 2
177 | SJ201 | SJ_0805 (DNP) | SJ_0805 | SJ, 0805 (DNP) | SJ | 1 |  |  |  | 2
178 | SJ300 | SJ_0805 (DNP) | SJ_0805 | SJ, 0805 (DNP) | SJ | 1 |  |  |  | 2
179 | SJ301 | SJ_0805 (DNP) | SJ_0805 | SJ, 0805 (DNP) | SJ | 1 |  |  |  | 2
180 | SJ700 | SJ_1206 (DNP) | SJ_1206 | SJ, 1206 (DNP) | SJ | 1 |  |  |  | 2 | A big fat solder jumper for high-current
181 | J600 | SOK_2x10_100TH_THT | OV5642_HDR_2x10 | SOK_2x10_100TH_THT | CAMERA_2x10 | 1 |  |  |  | 20 | OV5642 camera 100TH pin header 2x10 vertical
182 | U100 | STM32F429ZIT6 | TSQFP50P2200X2200X160-144M | STM32F429ZIT6, LQFP-144 | STM32F429 | 1 |  | STM32F429 |  | 144 | TSQFP, 144-Leads, Body 20.00x20.00mm, Pitch 0.50mm, STM32F429
183 | TP105 | TP_LARGE (DNP) | TP_LARGE | TP (DNP) | TP_LARGE | 1 |  |  |  | 1 | 5016
184 | TP106 | TP_LARGE (DNP) | TP_LARGE | TP (DNP) | TP_LARGE | 1 |  |  |  | 1 | 5016
185 | TP200 | TP_LARGE (DNP) | TP_LARGE | TP (DNP) | TP_LARGE | 1 |  |  |  | 1 | 5016
186 | TP303 | TP_LARGE (DNP) | TP_LARGE | TP (DNP) | TP_LARGE | 1 |  |  |  | 1 | 5016
187 | TP702 | TP_LARGE (DNP) | TP_LARGE | TP (DNP) | TP_LARGE | 1 |  |  |  | 1 | 5016
188 | TP100 | TP_SMALL (DNP) | TP_SMALL | TP (DNP) | TP_SMALL | 1 |  |  |  | 1 | 5015
189 | TP101 | TP_SMALL (DNP) | TP_SMALL | TP (DNP) | TP_SMALL | 1 |  |  |  | 1 | 5015
190 | TP104 | TP_SMALL (DNP) | TP_SMALL | TP (DNP) | TP_SMALL | 1 |  |  |  | 1 | 5015
191 | TP203 | TP_SMALL (DNP) | TP_SMALL | TP (DNP) | TP_SMALL | 1 |  |  |  | 1 | 5015
192 | TP204 | TP_SMALL (DNP) | TP_SMALL | TP (DNP) | TP_SMALL | 1 |  |  |  | 1 | 5015
193 | TP205 | TP_SMALL (DNP) | TP_SMALL | TP (DNP) | TP_SMALL | 1 |  |  |  | 1 | 5015
194 | TP207 | TP_SMALL (DNP) | TP_SMALL | TP (DNP) | TP_SMALL | 1 |  |  |  | 1 | 5015
195 | TP208 | TP_SMALL (DNP) | TP_SMALL | TP (DNP) | TP_SMALL | 1 |  |  |  | 1 | 5015
196 | TP209 | TP_SMALL (DNP) | TP_SMALL | TP (DNP) | TP_SMALL | 1 |  |  |  | 1 | 5015
197 | TP300 | TP_SMALL (DNP) | TP_SMALL | TP (DNP) | TP_SMALL | 1 |  |  |  | 1 | 5015
198 | TP301 | TP_SMALL (DNP) | TP_SMALL | TP (DNP) | TP_SMALL | 1 |  |  |  | 1 | 5015
199 | TP302 | TP_SMALL (DNP) | TP_SMALL | TP (DNP) | TP_SMALL | 1 |  |  |  | 1 | 5015
200 | TP304 | TP_SMALL (DNP) | TP_SMALL | TP (DNP) | TP_SMALL | 1 |  |  |  | 1 | 5015
201 | TP305 | TP_SMALL (DNP) | TP_SMALL | TP (DNP) | TP_SMALL | 1 |  |  |  | 1 | 5015
202 | TP306 | TP_SMALL (DNP) | TP_SMALL | TP (DNP) | TP_SMALL | 1 |  |  |  | 1 | 5015
203 | TP600 | TP_SMALL (DNP) | TP_SMALL | TP (DNP) | TP_SMALL | 1 |  |  |  | 1 | 5015
204 | TP601 | TP_SMALL (DNP) | TP_SMALL | TP (DNP) | TP_SMALL | 1 |  |  |  | 1 | 5015
205 | TP700 | TP_SMALL (DNP) | TP_SMALL | TP (DNP) | TP_SMALL | 1 |  |  |  | 1 | 5015
206 | TP701 | TP_SMALL (DNP) | TP_SMALL | TP (DNP) | TP_SMALL | 1 |  |  |  | 1 | 5015
207 | TP500 | TP_TINY (DNP) | TP_TINY | TP (DNP) | TP_TINY | 1 |  |  |  | 1 | 1mm round tiny testpoint
208 | TP501 | TP_TINY (DNP) | TP_TINY | TP (DNP) | TP_TINY | 1 |  |  |  | 1 | 1mm round tiny testpoint

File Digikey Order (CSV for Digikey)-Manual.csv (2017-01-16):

DigikeyPN | Quantity | Designator | Value | PartNumber | Comment | Footprint | Description | LibRef | Library Reference | LoadCapacitance | Model:Footprint | Pins | ScrewSize | VisibleNetName
732-7046-1-ND | 9 | SW100, SW101, SW700 |  | 434121043816 | BTN0, RESET, RESET | 4341x10438x6 | WS-TASV 6.0x3.5 mm SMD | WS-TASV, 434121043816 | WS-TASV, 434121043816 |  | 6.0*3.5mm vertical type, SMD, height 4.3mm, white actuator, 260gf, T&R | 2
638-1120-1-ND | 3 | U301 |  | EMC1412-1-ACZL-TR |  | TSOP65P490X110-8N | Dual channel I2C temperature sensor | EMC1412 | EMC1412 |  | TSOP, 8-Leads, Body 3.00x3.00mm, Pitch 0.65mm (MSOP-8, MCP79412) | 8
706-1132-ND | 3 | U500 |  | IS42S16400J |  | TSOP80P1170X120-54N | 1Mb x 16 x 4 bank (64 Mbit) SDRAM | IS42S16400J | IS42S16400J |  | TSOP, 54-Leads, Body 22.22x10.16mm, (IS42S16400J) | 54
LT8608IMSE#PBF-ND | 3 | U400 |  | LT8608 |  | TSSOP50P490X110_HS-11N | 42V 1.5A step-down, low Iq | LT8608 | LT8608 |  | TSSOP, 10-Leads, Body 3.00x3.00mm, Pitch 0.50mm, Thermal Pad 1.88x1.68mm, IPC Medium Density | 11
568-5818-1-ND | 10 | Q700, Q701 |  | 2N7002 |  | SOT95P240X100-3N (CMPSH1-4 TR) | N-Channel MOSFET | MOSFET-N | MOSFET-N |  | SOT23, 3-Leads, Body 2.90x2.40mm, | 3
MMBT3904LT1GOSCT-ND | 10 | Q300 |  | MMBT3904 |  | SOT90P240X110-3N | NPN General Purpose Amplifier | 2N3904 | 2N3904 |  | SOT23, 3-Leads, Body 2.90x2.40mm, Pitch 0.90mm, MMBT3904 | 3
LT3652HVIMSE#PBF-ND | 3 | U200 |  | LT3652 |  | TSOP65P490X110_HS-13N (LT3652) | MPPC and battery charger | LT3652 | LT3652 |  | TSOP, 12-Leads, Body 4.04x3.00mm, Pitch 0.65mm, Thermal Pad 2.95x1.76mm, | 13
36-9923-ND | 4 | MTGH1, MTGH2, MTGH3, MTGH4 |  |  | MTGH | MTGH-M3x0.5 | Mounting hole | MTGH | MTGH |  | M3 x 0.5 pan head mounting hole | 1 | M3x0.5
732-5316-ND | 3 | JP200 |  |  | SHDN_EN | HDR_100TH_1x3 | 3-pos Jumper | JP-3 | JP-3 |  | 100TH pin header 1x3 vertical | 3
609-3264-ND | 3 | J700 |  |  | HDR_FTDI_EXTENDED | HDR1X8 |  | HDR_FTDI_EXTENDED | HDR_FTDI_EXTENDED |  | Connector | Header | 8 Position | 8
S6106-ND | 3 | J600 |  |  | CAMERA_2x10 | OV5642_HDR_2x10 | 20-pin parallel camera connector for OV5642 | CAMERA_2x10 | CAMERA_2x10 |  | OV5642 camera 100TH pin header 2x10 vertical | 20
732-5317-ND | 3 | J400 |  |  | EXT 3V3 | HDR1X4 | Header, 4-Pin | Header 4 | Header 4 |  | Connector | Header | 4 Position | 4
732-2770-ND | 3 | J203 |  | 691322110003 | 691322110003 | 691322110003 | WR-TBL Terminal block - serie 3221 - 3.50 mm | 691322110003 | 691322110003 |  | 3,50mm - PCB Horizontal - 03p | 3
535-9166-1-ND | 6 | Y101, Y300 |  | ABS25-32.768KHZ-T |  | XTAL-SOJ-4 |  | XTAL-SOJ-4 | XTAL-SOJ-4 | 12.5p |  | 4
LTC2943IDD#PBF-ND | 1 | U203 |  | LTC2943 |  | DFN8-3x3 | Multi-cell I2C fuel gauge | LTC2943A | LTC2943A |  | LTC2943 | 9
952-1770-ND | 15 | J201, J202, J204, JP700, JP701 |  |  | PV_IN, NTC, VBAT, JP-2, JP-2 | HDR1X2, HDR1X2, HDR1X2, HDR_100TH_1x2, HDR_100TH_1x2 | Header, 2-Pin, Header, 2-Pin, Header, 2-Pin, 2-pos Jumper, 2-pos Jumper | Header 2, Header 2, Header 2, JP-2, JP-2 | Header 2, Header 2, Header 2, JP-2, JP-2 |  | Connector; Header; 2 Position, Connector; Header; 2 Position, Connector; Header; 2 Position, 100TH pin header 1x2 vertical, 100TH pin header 1x2 vertical | 2
732-2769-ND | 3 | J200 |  | 691322110002 | 691322110002 | 691322110002 | WR-TBL Terminal block - serie 3221 - 3.50 mm | 691322110002 | 691322110002 |  | 3,50mm - PCB Horizontal - 02p | 2
497-14053-ND | 3 | U100 |  | STM32F429 | STM32F429 | TSQFP50P2200X2200X160-144M | Cortex-M4 microcontroller | STM32F429 | STM32F429 |  | TSQFP, 144-Leads, Body 20.00x20.00mm, Pitch 0.50mm, STM32F429 | 144
887-1263-1-ND | 3 | Y100 |  | 9C-8.000MEEJ-T |  | HC-49S | Crystal Oscillator | XTAL | XTAL | 18p | Crystal | 2
WM17452-ND | 6 | J103, J701 |  |  | HDR_SWD_2x6, ESP_GPIO | HDR_100TH_2X6_SMT | 6 pin SWD connector with +6 GND pins, Header, 6-Pin, Dual row | HDR_SWD_2x6, Header 6X2 | HDR_SWD_2x6, Header 6X2 |  | 100TH pin header, 2x6, SMT | 12
WM17454-ND | 3 | J102 |  |  | GPIO | HDR_100TH_2X8_SMT | Header, 8-Pin, Dual row | Header 8X2 | Header 8X2 |  | 100TH pin header, 2x8, SMT | 16
LTC2055HMS8#PBF-ND | 3 | U302 |  | LTC2055 |  | TSOP65P490X110-8N | Dual zero-drift op amp | LTC2054/LTC2055 | LTC2054/LTC2055 |  | TSOP, 8-Leads, Body 3.00x3.00mm (LTC2054/LTC2055) | 8
MCP79412-I/MS-ND | 3 | U300 |  | MCP79412 |  | TSOP65P490X110-8N | I2C RTC w/ SRAM and EEPROM | MCP7941x | MCP7941x |  | TSOP, 8-Leads, Body 3.00x3.00mm, Pitch 0.65mm (MSOP-8, MCP79412) | 8
609-3263-ND | 6 | J100, J101 |  |  | HDR_FTDI | HDR_100TH_1x6 | Sparkfun FTDI pinout connector | HDR_FTDI | HDR_FTDI |  | 100TH pin header 1x6 vertical | 6
732-4978-1-ND | 25 | D301, D302, D303, D304, D305, D400 |  |  | 0603, 0603, 0603, 0603, 0603, 3V3 | LED_0603 | Typical INFRARED GaAs LED, Typical INFRARED GaAs LED, Typical INFRARED GaAs LED, Typical INFRARED GaAs LED, Typical INFRARED GaAs LED, [NoValue] | LED0 | LED0 |  |  | 2
732-4971-1-ND | 10 | D203, D204, D300 |  |  | CHRG, FAULT, 0603 | LED_0603 | [NoValue], [NoValue], Typical INFRARED GaAs LED | LED0 | LED0 |  |  | 2
CMPSH1-4 CT-ND | 3 | D202 |  | CMPSH1-4 |  | SOT95P240X100-3N (CMPSH1-4 TR) | Schottky Diode | D Schottky | D Schottky |  | SOT23, 3-Leads, Body 2.90x2.40mm, | 2
CMSH3-40MA TR13CT-ND | 6 | D200, D201 |  | CMSH3-40MA |  | SODFL519X262-2N (CMSH3-40MA) | Schottky Diode | D Schottky | D Schottky |  | SODFL, 2-Leads, Body 2.60x5.19mm, | 2
36-5016CT-ND | 0 | TP105, TP106, TP200, TP206, TP303, TP401, TP702 |  |  | TP_LARGE | TP_LARGE |  | TP_LARGE | TP_LARGE |  | 5016 | 1 |  | GND
497-1549-1-ND | 6 | U201, U202 |  | LM234SM |  | SOIC127P600X175-8N (LM234) | Adjustable current source | LM234 | LM234 |  | SOIC, 8-Leads, Body 4.90x3.90mm, Pitch 1.27mm, | 3
36-5015CT-ND | 0 | TP100, TP101, TP102, TP103, TP104, TP201, TP203, TP204, TP205, TP207, TP208, TP209, TP300, TP301, TP302, TP304, TP305, TP306, TP307, TP308, TP309, TP400, TP600, TP601, TP700, TP701 |  |  |  | TP_SMALL |  | TP_SMALL | TP_SMALL |  | 5015 | 1 |  | TX, RX, TX, RX, 3V3, VIN, VBAT_INT, VINFB, VFB, VBAT, CHRG, FAULT, SDA, SCL, ALERT, SPECT0, SPECT1, LED0, LED1, LED2, LED3, 3V3, SDA, SCL, TX, RX
317060015-ND | 0 | U700 |  | ESP8266-12E |  | ESP8266 ESP-12-E | ESP8266 ESP-12-E | ESP8266 ESP-12-E | ESP8266 ESP-12-E |  | ESP8266 ESP-12-E | 22
36-5106CT-ND | 0 | R400, R403, R707 | 0 |  | 1206 | RES_1206 | Resistor | Res1 | Res1 |  |  | 2
311-0.0ARCT-ND | 10 | R100, R103 | 0, 220 |  | 805 | RES_0805 | Resistor | Res1 | Res1 |  |  | 2
311-1.00MCRCT-ND | 10 | R401 | 1M |  | 805 | RES_0805 | Resistor | Res1 | Res1 |  |  | 2
311-1.00MLRCT-ND | 10 | R303, R308 | 1M |  | 402 | RES_0402 | Resistor | Res1 | Res1 |  |  | 2
311-1.00KCRCT-ND | 10 | R202 | 1k |  | 805 | RES_0805 | Resistor | Res1 | Res1 |  |  | 2
1276-1020-1-ND | 10 | C700 | 1n |  | 805 | CAP_0805 | Capacitor | Cap | Cap |  |  | 2
1276-6470-1-ND | 10 | C200 | 1u |  | 0805,50V | CAP_0805 | Capacitor | Cap | Cap |  |  | 2
1276-6458-1-ND | 15 | C113, C114, C115, C407 | 2.2u |  | 805 | CAP_0805 | Capacitor | Cap | Cap |  |  | 2
311-2.40KCRCT-ND | 10 | R204 | 2.4k |  | 805 | RES_0805 | Resistor | Res1 | Res1 |  |  | 2
311-3.30KCRCT-ND | 25 | R300, R301, R302, R600, R601 | 3.3k |  | 805 | RES_0805 | Resistor | Res1 | Res1 |  |  | 2
SRR1260-3R3YCT-ND | 2 | L400 | 3.3u | SRR1260-3R3 |  | SRR1260 | Inductor | Inductor | Inductor |  |  | 2
1276-3343-1-ND | 10 | C201, C202, C203 | 4.7u |  | 1210,50V | CAP_1210 | Capacitor | Cap | Cap |  |  | 2
311-10.0KCRCT-ND | 50 | R211, R212, R700, R701, R702, R703, R706, R708, R711 | 10k |  | 805 | RES_0805 | Resistor | Res1 | Res1 |  |  | 2
1276-1015-1-ND | 10 | C408 | 10n |  | 805 | CAP_0805 | Capacitor | Cap | Cap |  |  | 2
1276-1109-1-ND | 10 | C403 | 10p |  | 805 | CAP_0805 | Capacitor | Cap | Cap |  |  | 2
1276-1312-1-ND | 25 | C205, C206, C401, C601, C702 | 10u |  | 1206,16V, 1206,16V, 1206,16V, 1206,16V, 1206 | CAP_1206 | Capacitor | Cap | Cap |  |  | 2
587-1295-1-ND | 10 | C404, C406 | 10u |  | 805 | CAP_0805 | Capacitor | Cap | Cap |  |  | 2
SRR1208-150MLCT-ND | 2 | L200 | 15u | SRR1208-150ML |  | srr1208 | Inductor | Inductor | Inductor |  |  | 2
490-6203-1-ND | 15 | C102, C103, C300, C301 | 18p |  | 402 | CAP_0402 | Capacitor | Cap | Cap |  |  | 2
311-24.3KCRCT-ND | 10 | R206 | 24.3k |  | 805 | RES_0805 | Resistor | Res1 | Res1 |  |  | 2
CSR1206FK25L0CT-ND | 5 | R210 | 25m |  | 1206 | RES_1206 | Resistor | Res1 | Res1 |  |  | 2
1276-1153-1-ND | 10 | C100, C101 | 27p |  | 402 | CAP_0402 | Capacitor | Cap | Cap |  |  | 2
311-33.2KCRCT-ND | 10 | R405 | 33.2k |  | 805 | RES_0805 | Resistor | Res1 | Res1 |  |  | 2
1276-3063-1-ND | 12 | C405, C600, C701 | 47u |  | 1206,10V | CAP_1206 | Capacitor | Cap | Cap |  |  | 2
CRA6S868CT-ND | 25 | RR503, RR504, RR505, RR506 | 49.9 |  | RES_ARR_4 | CAC-80P319X150-8M | 4 element resistor array | RES_ARR_4 | RES_ARR_4 |  | Chip Array, ConvexS, 8-Leads, Pitch 0.80mm, Body 3.20x1.50mm, for Vishay CRA06S | 8
CRA6S849.9ACT-ND | 25 | RR500, RR501, RR502, RR507, RR508 | 49.9 |  | RES_ARR_4 | CAC-80P319X150-8M | 4 element resistor array | RES_ARR_4 | RES_ARR_4 |  | Chip Array, ConvexS, 8-Leads, Pitch 0.80mm, Body 3.20x1.50mm, for Vishay CRA06S | 8
311-49.9CRCT-ND | 50 | R110, R500, R501, R502, R602 | 49.9 |  | 805 | RES_0805 | Resistor | Res1 | Res1 |  |  | 2
311-54.9KCRCT-ND | 10 | R207 | 54.9k |  | 805 | RES_0805 | Resistor | Res1 | Res1 |  |  | 2
WSLC-.08CT-ND | 5 | R200 | 80m |  | 1206 | RES_1206 | Resistor | Res1 | Res1 |  |  | 2
311-100CRCT-ND | 25 | R101, R102, R104, R105, R704, R705, R709, R710 | 100 |  | 805 | RES_0805 | Resistor | Res1 | Res1 |  |  | 2
311-100KCRCT-ND | 25 | R208, R209, R402 | 100k |  | 805 | RES_0805 | Resistor | Res1 | Res1 |  |  | 2
587-3498-1-ND | 100 | C104, C105, C106, C107, C108, C109, C110, C111, C112, C116, C117, C118, C119, C120, C121, C122, C123, C124, C204, C302, C303, C400, C402, C500, C501, C502, C503, C504, C505, C506, C507 | 100n |  | 402 | CAP_0402 | Capacitor | Cap | Cap |  |  | 2
311-105KCRCT-ND | 10 | R203 | 105k |  | 805 | RES_0805 | Resistor | Res1 | Res1 |  |  | 2
311-215KCRCT-ND | 10 | R205 | 215k |  | 805 | RES_0805 | Resistor | Res1 | Res1 |  |  | 2
490-1293-1-ND | 10 | C304, C305 | 220p |  | 402 | CAP_0402 | Capacitor | Cap | Cap |  |  | 2
311-309KCRCT-ND | 10 | R404 | 309k |  | 805 | RES_0805 | Resistor | Res1 | Res1 |  |  | 2
311-330CRCT-ND | 25 | R304, R305, R306, R307, R406 | 330 |  | 805 | RES_0805 | Resistor | Res1 | Res1 |  |  | 2
311-340KCRCT-ND | 10 | R201 | 340k |  | 805 | RES_0805 | Resistor | Res1 | Res1 |  |  | 2
311-510CRCT-ND | 10 | R109 | 510 |  | 805 | RES_0805 | Resistor | Res1 | Res1 |  |  | 2

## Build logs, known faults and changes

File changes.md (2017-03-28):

# Changelog and Notes

## SOLENS rev. A (first PCB)

#### Rev. A PCB/schematic issues

* Power LED on wrong side of R400/R403, power LED should illuminate when 3V3 buck is on, regardless of rest of board. (done)
* TP\_TINY footprint has paste mask and shouldn't (fixed)
    * TP202 got paste
    * TP500 got paste
    * TP501 got paste
* 0402 footprints need a slight change of shape, pads should be slightly closer together and enlarged slightly (fixed)
    * This should fix the few tombstoned capacitors
    * Pad size was: 0.8 mm (X) x 0.6 mil (Y)
* Fuel gauge footprint (DFN) needs larger pads (more paste volume) for better reflow (fixed)
    * Pad size was: 0.25 mm (X) x 0.7 mm (Y)
* Fuel gauge is mis-wired, only senses current _into_ battery. (fixed)
* SDRAM data (DQ*) termination is listed as 49R9, should be 33R per Hyperlynx sims (fixed)
* Slight undershoot issue on camera parallel interface (need scope captures to document)
    * Add termination arrays on all camera interface lines, value unknown (need to rework SJ* on bus before value decision)
    * SJ replaced by termination, 33R determined as suitable termination value (done)
* LT3652 charging circuit had regulation issues (bad/damaged chip?)
* XCLK termination (R602) is on the wrong end of the line, need to be near MCU (fixed)

#### Rev. A assembly issues

* U203 pin 1 looks unconnected
* U203 most pads have poor fillets
* C504 east pad cold
* C503 west pad cold
* C109 west pad cold
* U100 pin 124 poor fillet
* J102 poor alignment

#### Rev. A wishlist

* Use stainless steel stencil instead of polyimide
* Shrink inductor sizes (done)
* Move components to back, particularly current sources (done)
* Switch 2- and 3-pos Pheonix to single 5-pos Pheonix (done)
* Replace WiFi UART jumpers to 2x2 header (done)
* Reduce wasted board space (done enough)
* Change selected power jumpers to solder jumpers i.e. they should be NC instead of NO (done)
* Clean up SDRAM schematic sheet (done)
* LT3652 charging circuit:
    * Change output voltage circuit to tracking-optional (done)
    * Change input voltage to non-temperature compensated, adjustable MPP voltage (done)
    * See Sparkfun Sunny Buddy for more flexible circuit
* Change LT8608 switching frequency (move out of AM broadcast band, > 1.7 MHz) (done)
* ~~Change WiFi UART connection between MCU-ESP from RXD0/TXD0 to RXD2/TXD2 (done)~~
* (Keep WiFi UART to MCU UART on RXD0/TXD0, for esp-link firmware) (done)
* Move SJ200 (LT3652 TIMER solder jumper) to bottom (done)
* Move WiFi GPIO header to bottom, make DNP (done)
* Move MCU GPIO header to bottom, make DNP (done)
* Add board dimensions to top overlay (done)
* Add screw hole sizes/coordinates to bottom overlay (done)
* Remove extraneous testpoints, solder jumpers, and debug circuitry where possible (done)
* Add chamfered corners, adjusting screw hole footprints as necessary (done)
* Connect PV voltage through voltage divider to MCU ADC input for monitoring (done)

## SOLENS rev. A -> B changelog

* Moved D400 (3V3 power LED) to regulator side of 3V3 jumpers.
* Fixed fuel gauge wiring, renaming VBAT to VBAT_INT where appropriate.
* Cleaned up SDRAM schematic page
* Updated SDRAM data termination arrays to 33R
* Added termination resistor arrays to camera data and control lines (still not sure on value)
* Removed paste mask from TP_TINY
* Changed 0402 pad dimensions to 0.9 mm (X) x 0.6m mil (Y), no pad spacing changes
* Changed DFN8-3X3 pad dimensions to 0.25 mm (X) x 0.9 mm (Y), moving pads away from center to preserve ePad to pad spacing
* Removed R208, R209 (CHRG and FAULT 100k pullups)
* Removed input tracking circuitry from LT3652, preparing for updated tracking circuit
* Updated input tracking circuitry (now with trimpot!)
* Simplified output voltage set circuitry
* Combined PV input and battery connector into a single 5-pin Euroblock
* Updated LT3652 inductor selection to Taiyo Yuden NRS8040T150MJGJ
* Updated LT8608 inductor selection to Taiyo Yuden NR6028T2R2N
* Changed WiFi MCU-ESP UART to UART2 (programming on UART0)
* WiFi is now powered by default
* Added optional LT3652 tempco charging circuit
* Shrunk both power sections
* Shrunk WiFi section, changed WiFi GPIO header to bottom/DNP
* Rotated camera footprint placement by 180 deg, connector is now near board edge
* Shrank board dimensions, both vertically and horizontally
* Connected PV panel input voltage through voltage divider to MCU ADC input for monitoring
* Added two (optionally-bridged) GPIO between MCU and WiFi per BH suggestion

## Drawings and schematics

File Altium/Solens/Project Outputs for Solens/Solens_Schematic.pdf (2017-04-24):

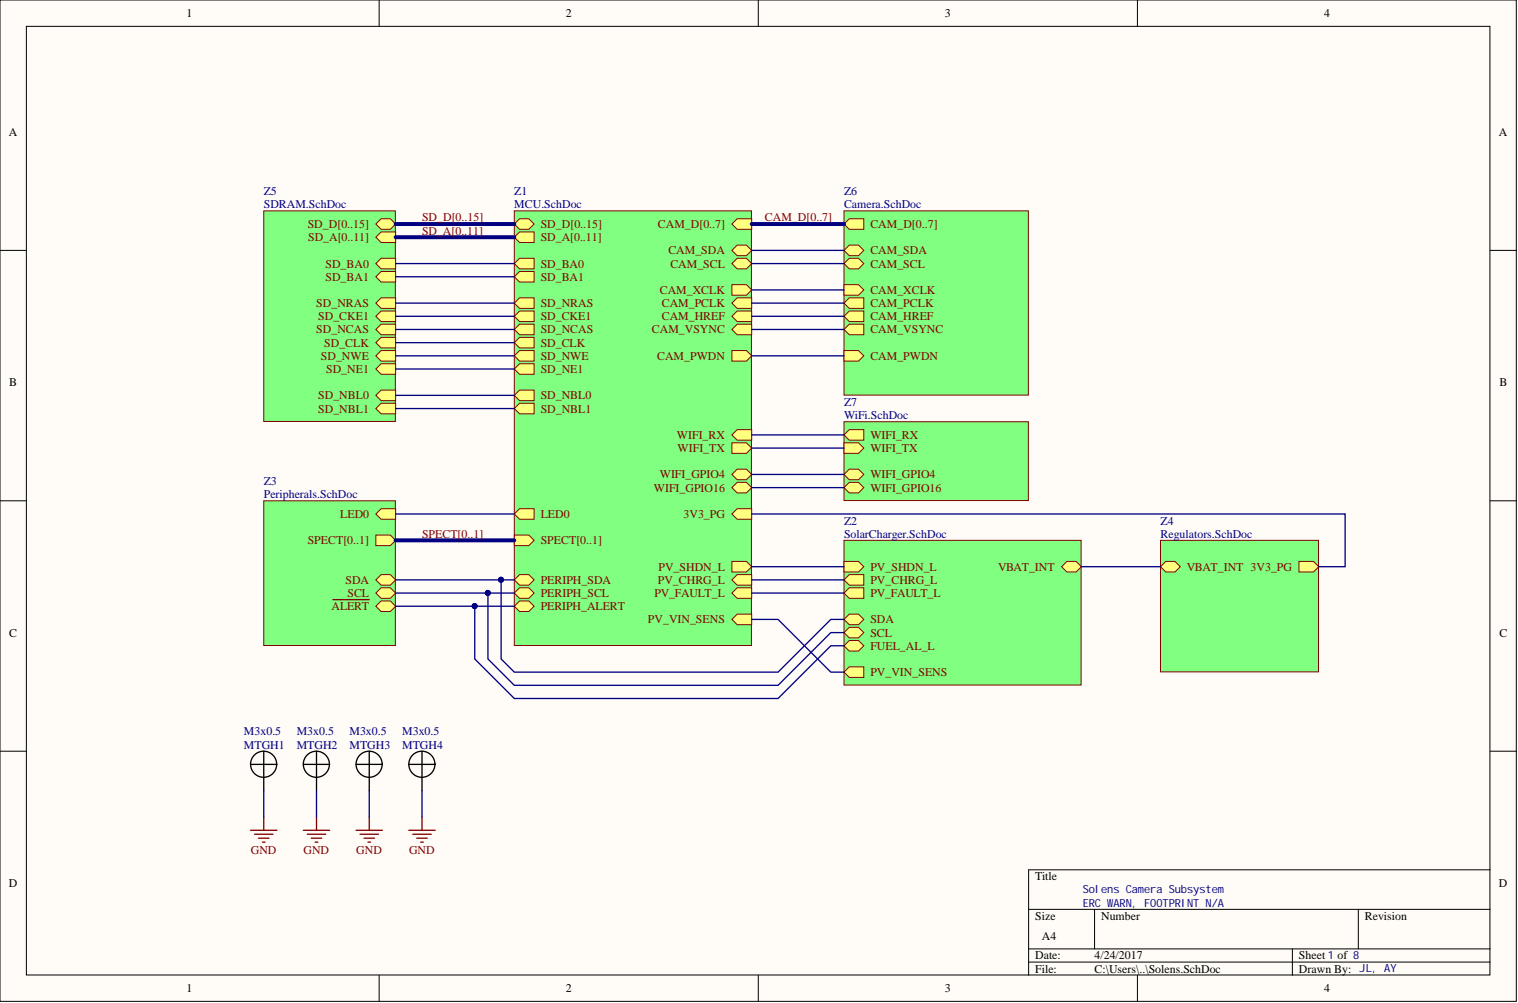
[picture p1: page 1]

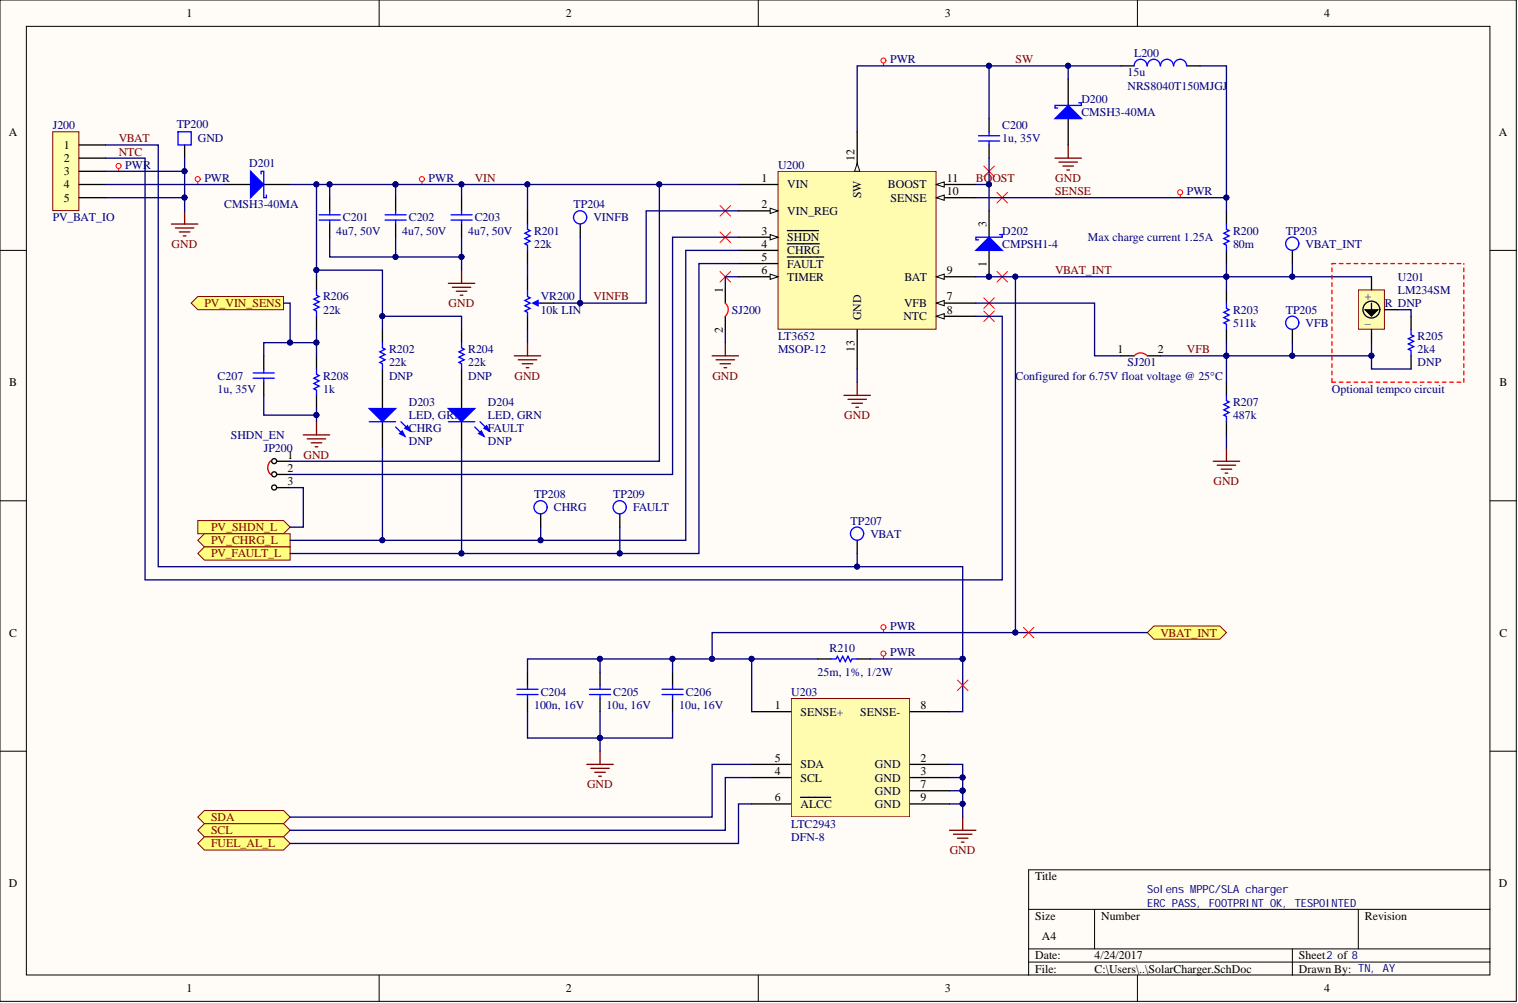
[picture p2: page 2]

C201 | | | | TP204 | | VIN_REG 2

VINFB | | | SHDN 3

VR200 | | VINFB | | CHRG 4

FAULT 5

VFB | 7

Configured for 6.75V float voltage @ 25°C

Solens MPPC/SLA charger
ERC PASS, FOOTPRINT OK, TESPOINTED

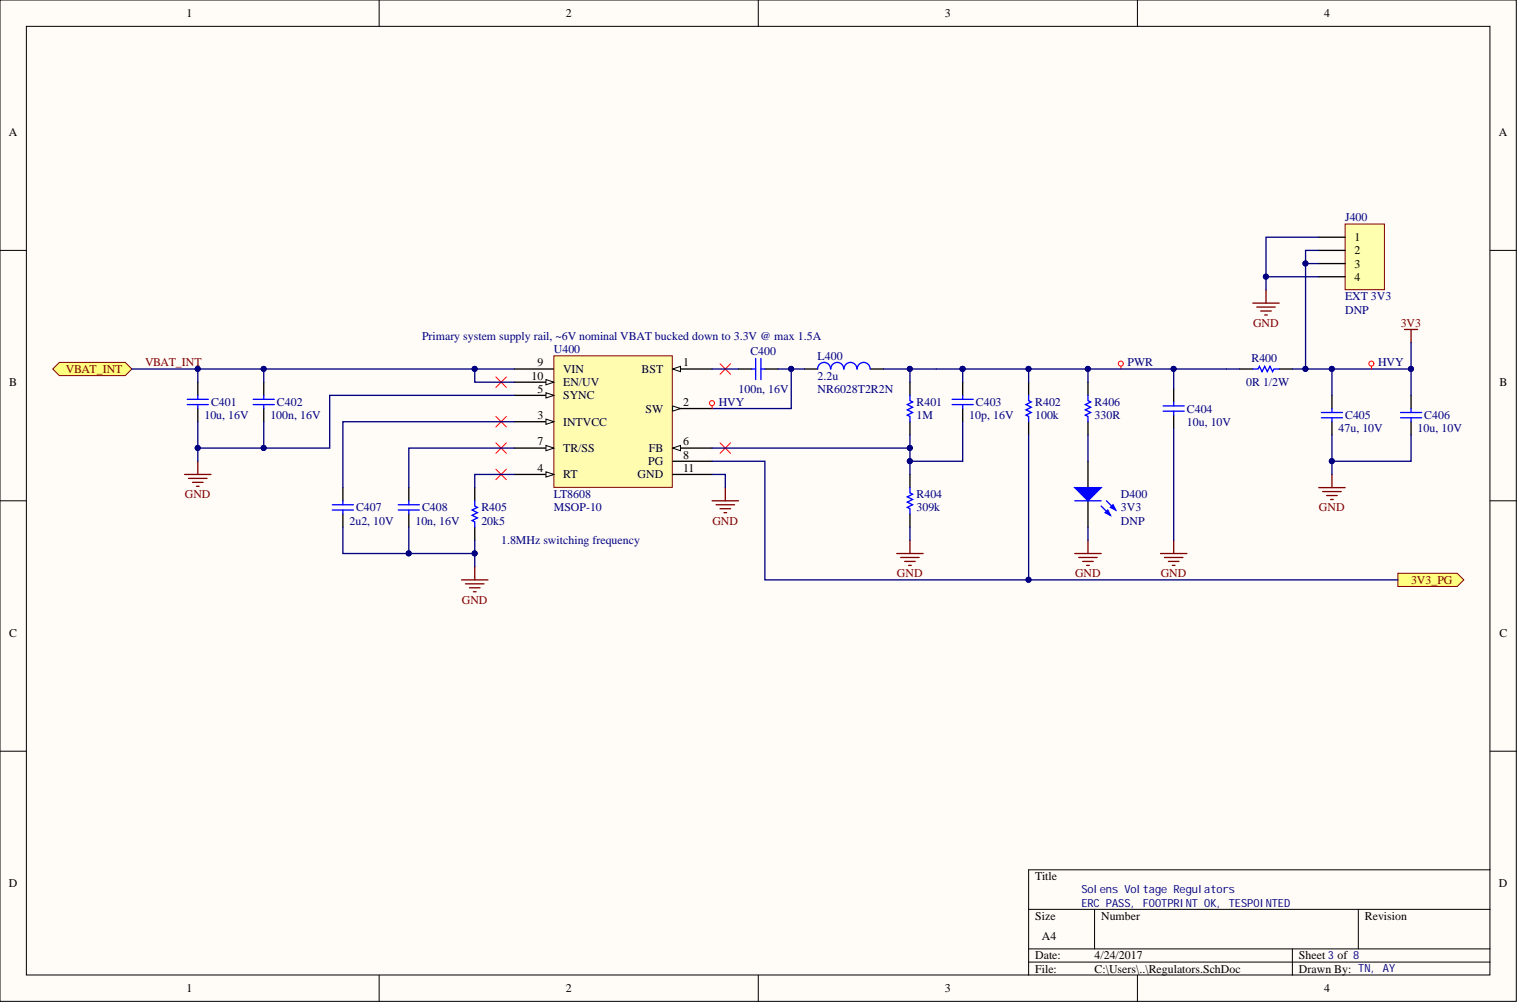
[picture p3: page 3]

Primary system supply rail, ~6V nominal VBAT bucked down to 3.3V @ max 1.5A

Solens Voltage Regulators
ERC PASS, FOOTPRINT OK, TESPOINTED

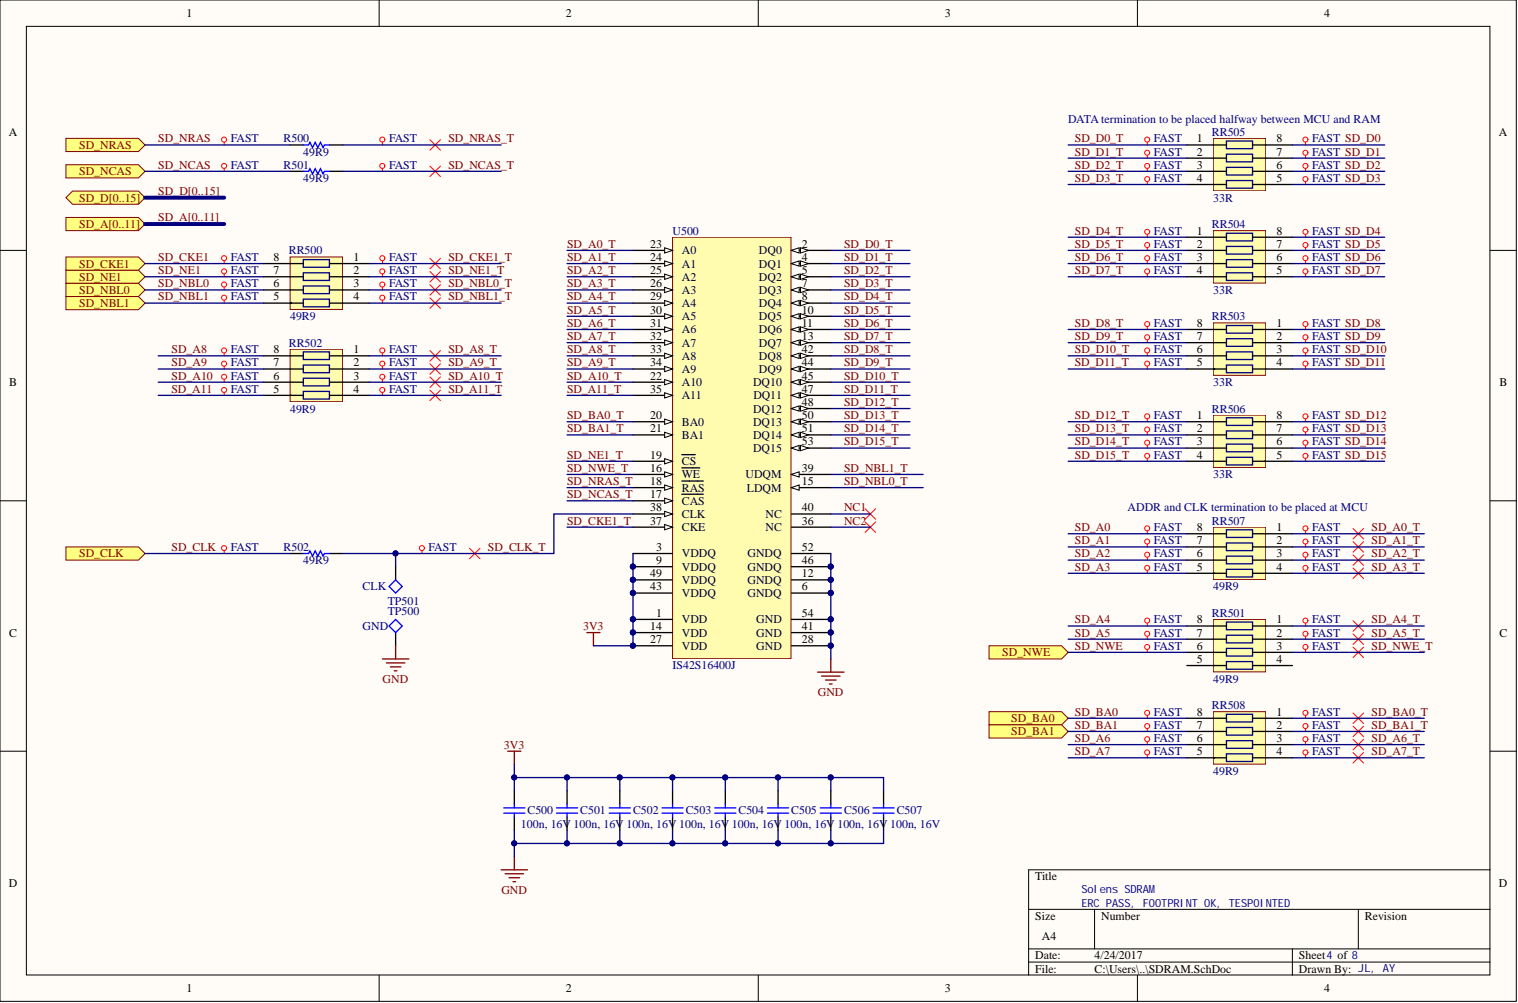
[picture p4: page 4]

DATA termination to be placed halfway between MCU and RAM

FAST FAST

FAST FAST FAST FAST FAST FAST

FAST FAST FAST FAST FAST
FAST

FAST FAST FAST

Solens SDRAM
ERC PASS, FOOTPRINT OK, TESPOINTED

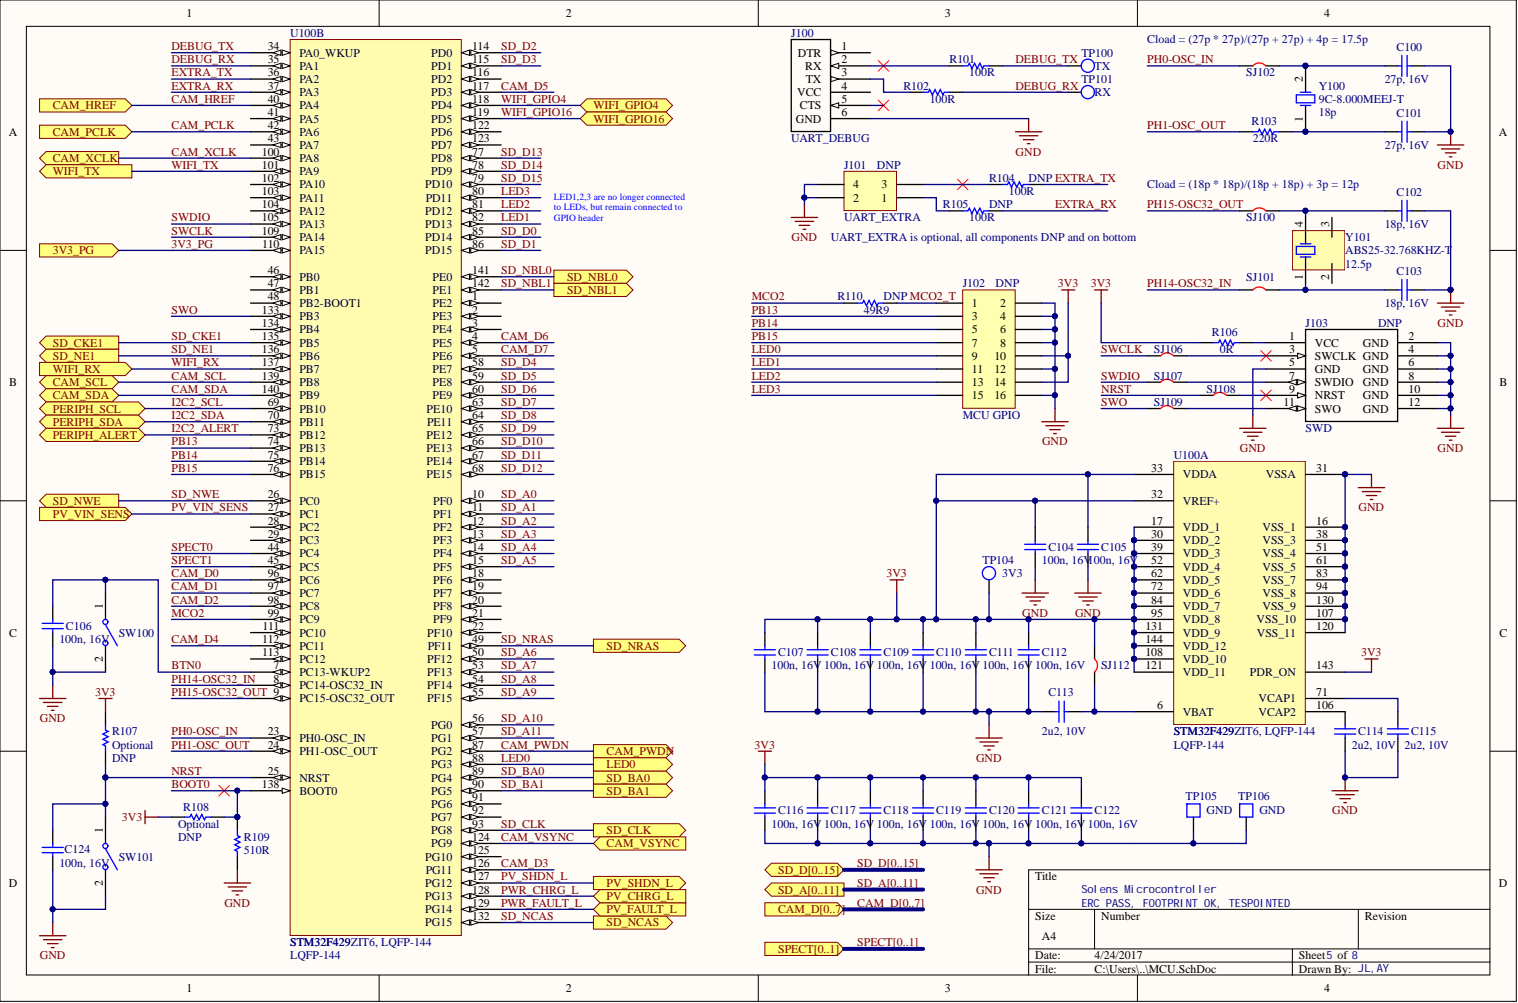
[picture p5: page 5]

DNP
UART_EXTRA
UART_EXTRA is optional, all components DNP and on bottom

LED1,2,3 are no longer connected
to LEDs, but remain connected to
GPIO header

VDD_9 131

Solens Microcontroller
ERC PASS, FOOTPRINT OK, TESPOINTED

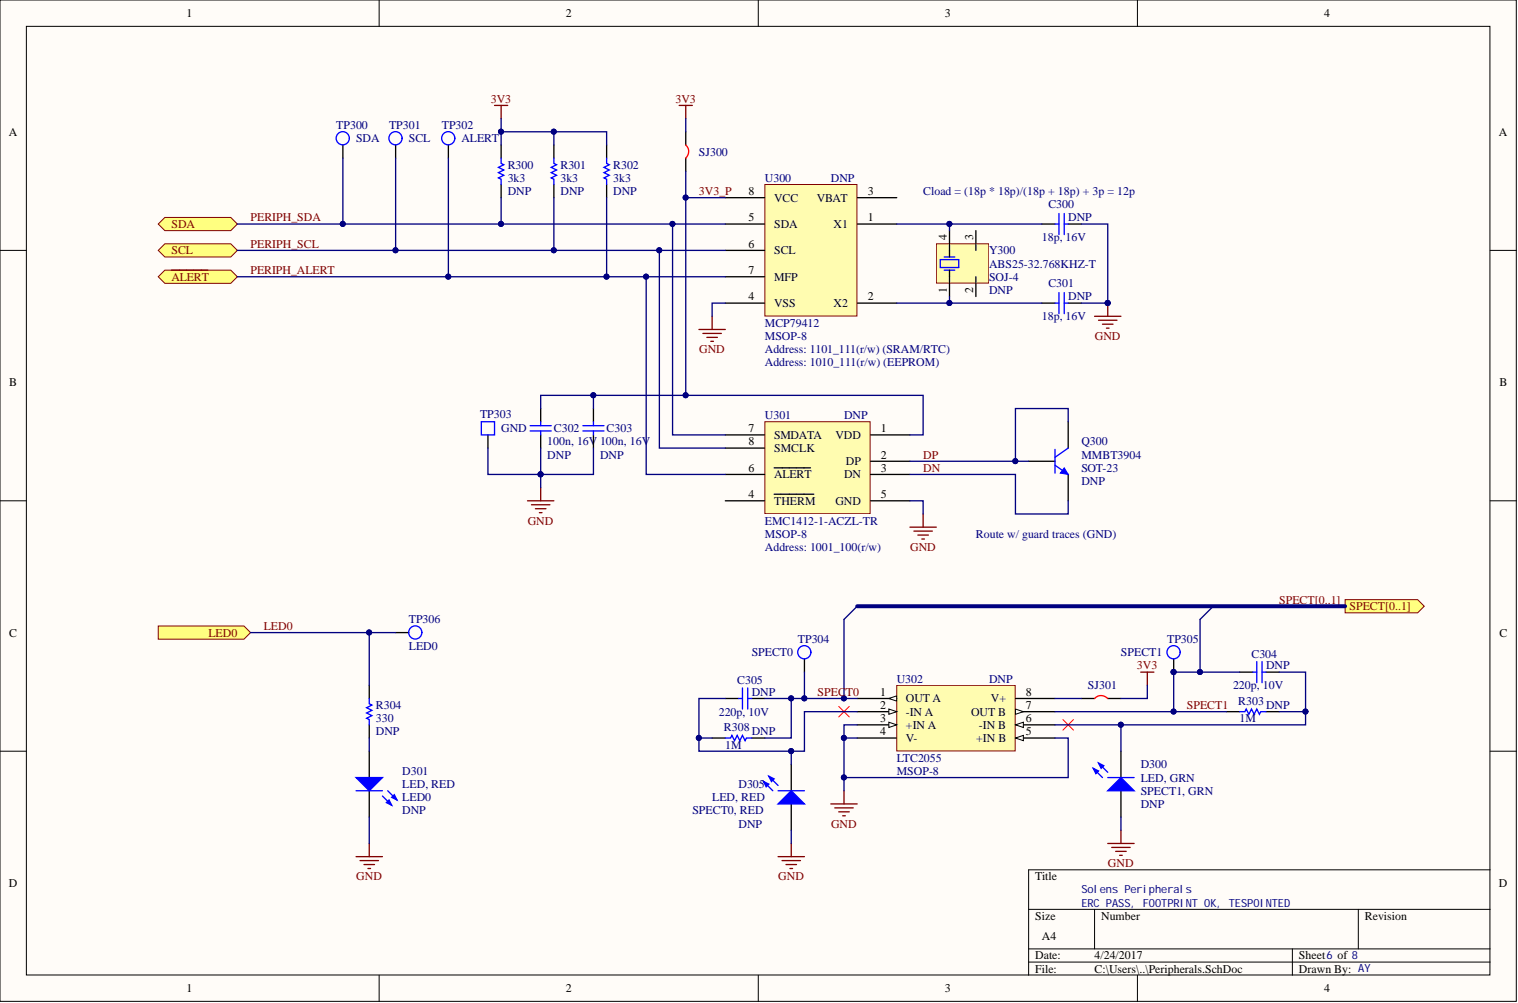
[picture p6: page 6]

Route w/ guard traces (GND)

220p, 10V R308 DNP 1M | -IN A 2

Solens Peripherals
ERC PASS, FOOTPRINT OK, TESPOINTED

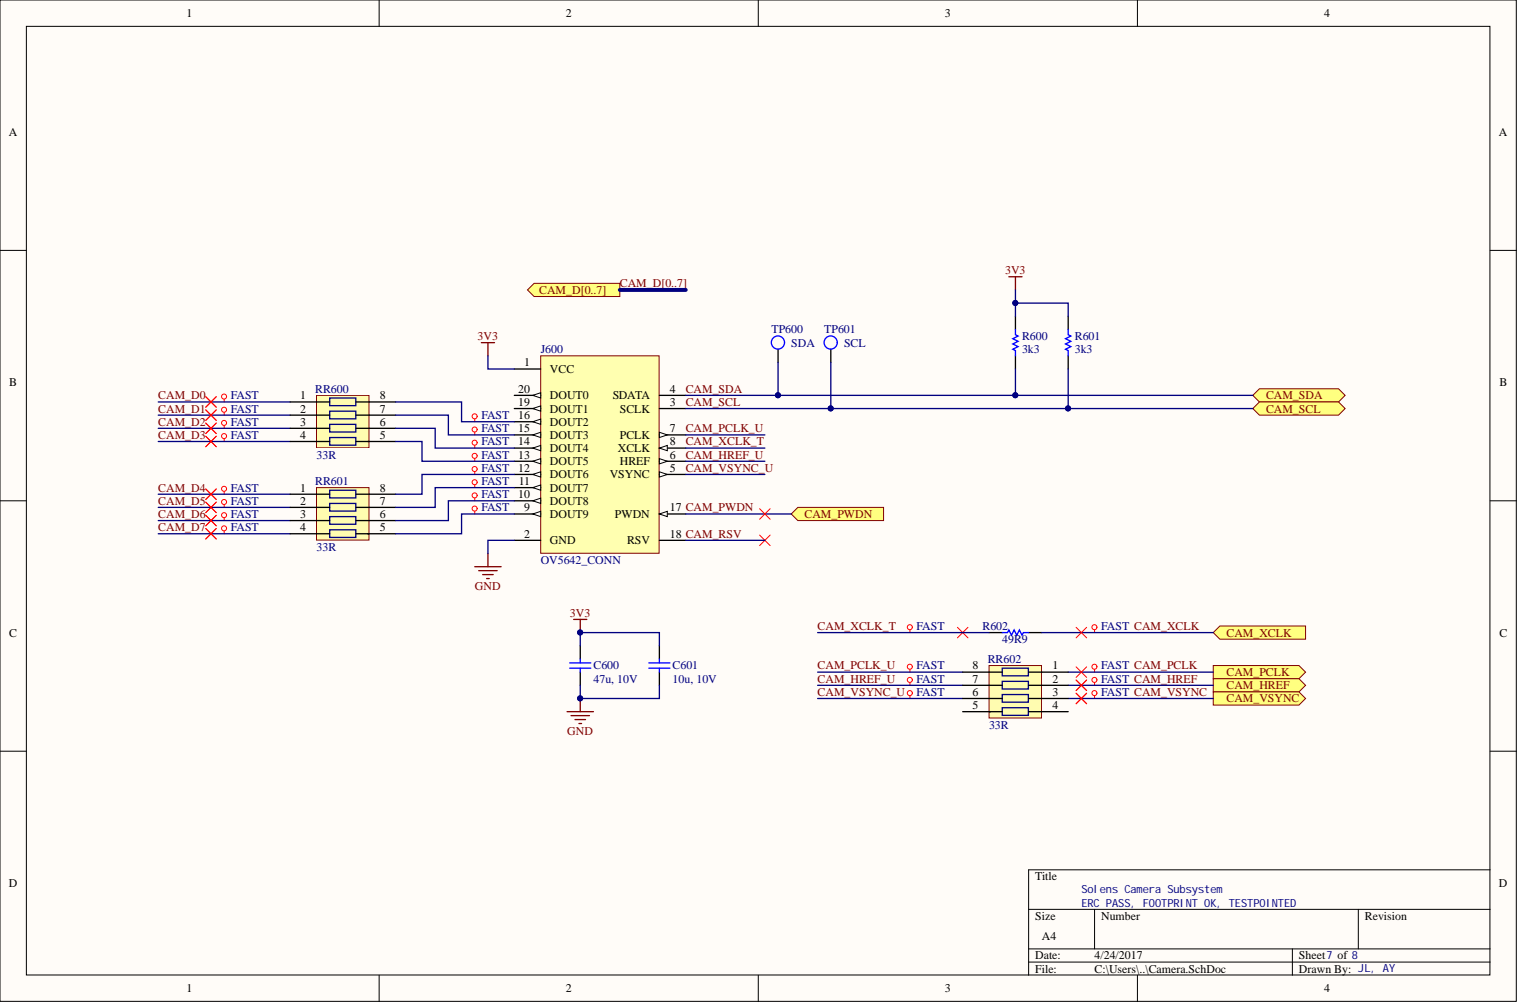
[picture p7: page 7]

6 | FAST

FAST | | DOUT9 9 DOUT8 10 DOUT7 11 DOUT6 12 DOUT5 13 DOUT4 14 DOUT3 15 DOUT2 16
FAST

GND 2

Solens Camera Subsystem
ERC PASS, FOOTPRINT OK, TESTPOINTED

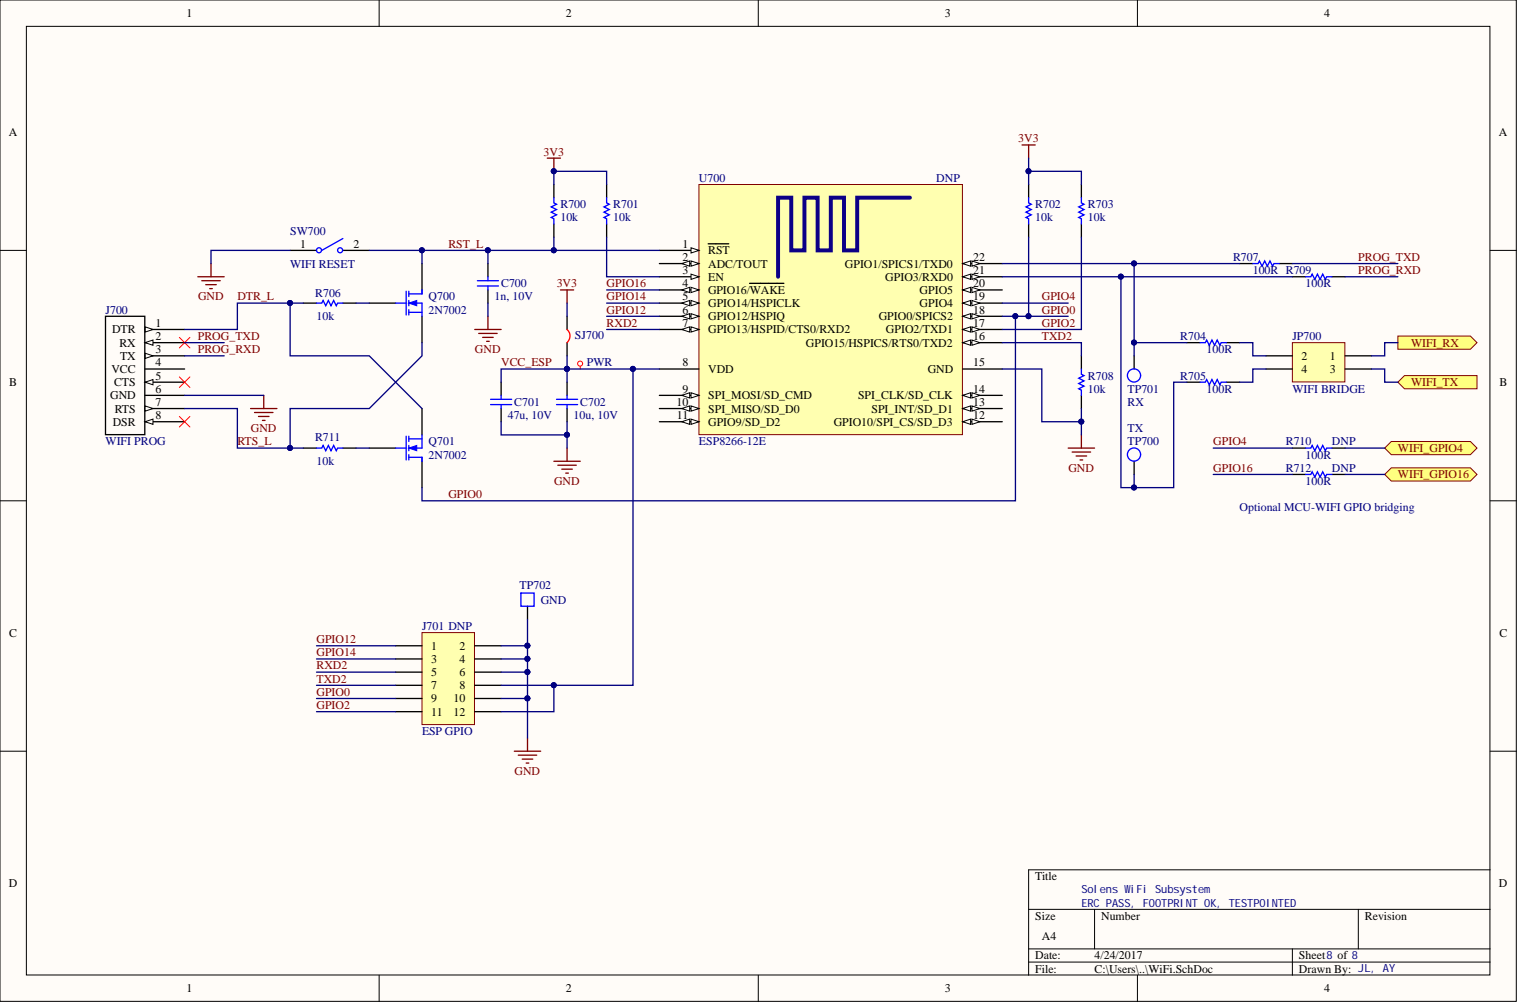
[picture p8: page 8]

Optional MCU-WIFI GPIO bridging

Solens WiFi Subsystem
ERC PASS, FOOTPRINT OK, TESTPOINTED

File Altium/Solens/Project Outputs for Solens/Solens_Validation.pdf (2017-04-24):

### Electrical Rules Check Report

Class | Document | Message
Warning | Solens.SchDoc | Nets Wire I2C2_ALERT has multiple names (Net Label I2C2_ALERT,Net Label
| | PERIPH_ALERT,Sheet Entry Z1-PERIPH_ALERT(I/O),Sheet Entry
Z2-FUEL_AL_L(I/O),Sheet Entry Z3-A\L\E\R\T\(I/O)) Warning | Solens.SchDoc | Nets Wire I2C2_SCL has multiple names (Net Label I2C2_SCL,Net Label
| | PERIPH_SCL,Sheet Entry Z1-PERIPH_SCL(I/O),Sheet Entry Z2-SCL(I/O),Sheet Entry
Z3-SCL(I/O)) Warning | Solens.SchDoc | Nets Wire I2C2_SDA has multiple names (Net Label I2C2_SDA,Net Label
| | PERIPH_SDA,Sheet Entry Z1-PERIPH_SDA(I/O),Sheet Entry Z2-SDA(I/O),Sheet Entry
Z3-SDA(I/O)) Warning | Solens.SchDoc | Nets Wire PERIPH_ALERT has multiple names (Sheet Entry Z1-PERIPH_ALERT(I/O),Sheet
| | Entry Z2-FUEL_AL_L(I/O),Sheet Entry Z3-A\L\E\R\T\(I/O))
Warning | Solens.SchDoc | Nets Wire PERIPH_SCL has multiple names (Sheet Entry Z1-PERIPH_SCL(I/O),Sheet Entry
| | Z2-SCL(I/O),Sheet Entry Z3-SCL(I/O))
Warning | Solens.SchDoc | Nets Wire PERIPH_SDA has multiple names (Sheet Entry Z1-PERIPH_SDA(I/O),Sheet Entry
| | Z2-SDA(I/O),Sheet Entry Z3-SDA(I/O))
Warning | Solens.SchDoc | Nets Wire PWR_CHRG_L has multiple names (Net Label PWR_CHRG_L,Sheet Entry
| | Z1-PV_CHRG_L(Input),Sheet Entry Z2-PV_CHRG_L(Output))
Warning | Solens.SchDoc | Nets Wire PWR_FAULT_L has multiple names (Net Label PWR_FAULT_L,Sheet Entry
| | Z1-PV_FAULT_L(Input),Sheet Entry Z2-PV_FAULT_L(Output))
Monday 24 Apr 2017 2:09:40 PM | Page 1 of 1

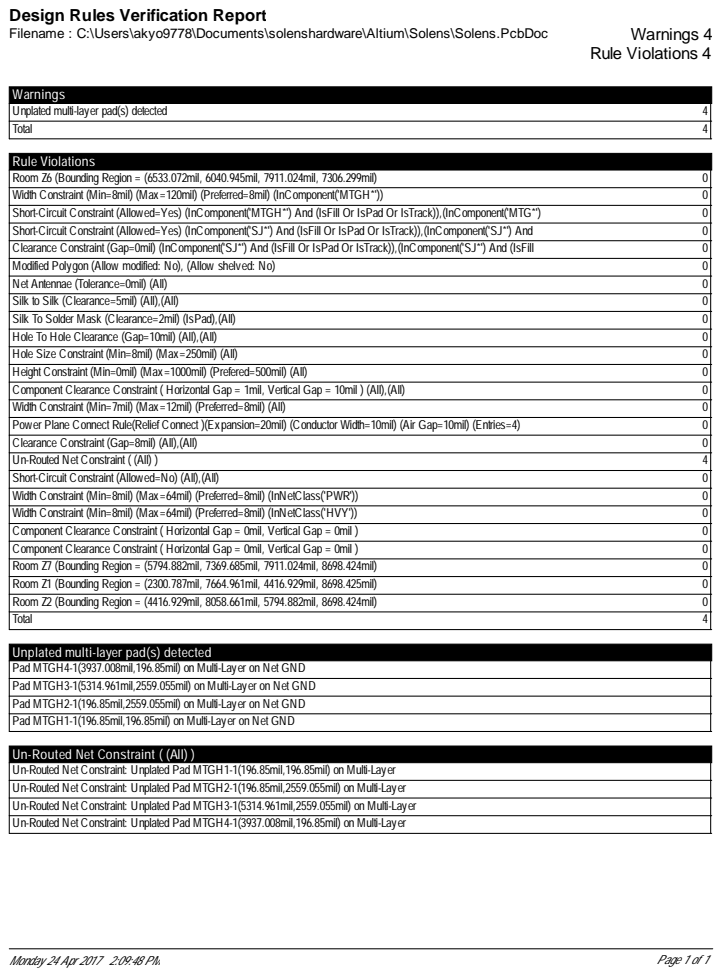
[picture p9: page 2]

Design Rules Verification Report

Unplated multi-layer pad(s) detected
Pad MTGH4-1(3937.008mil,196.85mil) on Multi-Layer on Net GND
Pad MTGH3-1(5314.961mil,2559.055mil) on Multi-Layer on Net GND
Pad MTGH2-1(196.85mil,2559.055mil) on Multi-Layer on Net GND
Pad MTGH1-1(196.85mil,196.85mil) on Multi-Layer on Net GND

Un-Routed Net Constraint ( (All) )
Un-Routed Net Constraint: Unplated Pad MTGH1-1(196.85mil,196.85mil) on Multi-Layer
Un-Routed Net Constraint: Unplated Pad MTGH2-1(196.85mil,2559.055mil) on Multi-Layer
Un-Routed Net Constraint: Unplated Pad MTGH3-1(5314.961mil,2559.055mil) on Multi-Layer
Un-Routed Net Constraint: Unplated Pad MTGH4-1(3937.008mil,196.85mil) on Multi-Layer

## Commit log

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2016-12-10 Adding camera jumpers/termination and cleaning up some parameters
    [Camera.SchDoc, SDRAM.SchDoc, Solens.PrjPCB]
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2016-12-10 Adding a custom BOM template and generating a BOM
    [MCU.SchDoc, Solens.PrjPCB]
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2016-12-10 Added blank PCB, configured stackup and board outline
    [Solens.PcbDoc]
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2016-12-10 Minor fixes (footprint and board outline), regenerating schematic and BOM
    [SolarCharger.SchDoc, Solens.PrjPCB]
2016-12-14 Starting PCB layout, fixing SJ and TQFP144 footprints
    [Camera.SchDoc, PcbLib1.PcbLib, Solens.PcbDoc]
2016-12-14 Beginning SDRAM-MCU layout, updating polygon and via defaults
    [Solens.PcbDoc]
2016-12-14 Missed a few changes
    [Solens.PrjPCB]
2016-12-15 More SDRAM routing, minor footprint updates, and beginning peripheral routing
    [MCU.SchDoc, PcbLib1.PcbLib, SDRAM.SchDoc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]
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2016-12-16 Fixed completely broken ESP8266-12E footprint. That's what we get for using 3rd party footprints...
    [Solens.PcbDoc, WiFi.SchDoc]
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2016-12-23 Adding planes for the converters, cleaning up power layouts
    [Solens.PcbDoc]
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2016-12-24 Routing camera, updating mounting hole footprints and design rules, other cleanup
    [Camera.SchDoc, PcbLib1.PcbLib, Schlib1.SchLib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]
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2016-12-27 Peripheral routing, more pinswaps, resized board outline, PDF updates
    [MCU.SchDoc, Solens.PcbDoc]
2016-12-29 Routing LED/TP stuff
    Altium Design v16.0.5, need to make sure this is compatible (or revert)
    [Solens.PcbDoc]
2016-12-29 Rerouted LED/TP stuff, ripped up UART_EXTRA
    Preparing to swap UART_EXTRA and UART_WIFI
    [Solens.PcbDoc]
2016-12-29 Swapped UART_EXTRA and UART_WIFI, misc routing
    [MCU.SchDoc, Solens.PcbDoc]
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2016-12-30 Added OV5642 footprint, updated PCB, fixed routing
    [Camera.SchDoc, PcbLib1.PcbLib, Solens.PcbDoc]
2016-12-30 Finally routed the SPECT traces
    Maybe if I commit this late at night nobody will question the SPECT
    chunk of circuit...
    [Solens.PcbDoc]
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2016-12-30 Broke some things, fixing paths and updating PDFs
    [Solens.PcbDoc, Solens.PrjPCB]
2016-12-30 Cleaning up DRC violations
    Disabled mask sliver checks temporarily, possibly permanently
    [PcbLib1.PcbLib, Peripherals.SchDoc, Solens.PcbDoc]
2016-12-30 Shrinking all refdes silk and starting conn labels
    [Solens.PcbDoc]
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2016-12-30 Cleaning up planes and updating PDFs
    Also fixed floating net label issue
    [MCU.SchDoc, Solens.PcbDoc]
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2017-01-07 Schematic changes from JL review, updating PCB
    RX/TX jumpers on WiFi-MCU lines; external 3V3 header; 3V3 power LED;
    FAULT/CHARGE LEDs; adding termination on MCO2
    [MCU.SchDoc, PcbLib1.PcbLib, Regulators.SchDoc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]
2017-01-07 Fixing DRC issues from the previous changes
    [Solens.PcbDoc]
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2017-01-10 Minor PCB tweaks and silk updates
    Preparing for Gerbering, testing DXF import of Solaire
    [Solens.PcbDoc]
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2017-01-13 Begin adding Digikey P/Ns to parts
    Screws, testpoints, ICs
    [Camera.SchDoc, MCU.SchDoc, Peripherals.SchDoc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]
2017-01-14 Adding more Digikey P/Ns and updating BOM outjob
    Mostly done except for res and caps. Added BOM output job specifically
    for Digikey upload
    [Bill of Materials (CSV for Digikey)-Solens.csv, Bill of Materials (CSV)-Solens.csv, Bill of Materials (XLSX)-Solens.xls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]
2017-01-14 More Digikey P/Ns
    About half of the R and C done
    [Camera.SchDoc, Peripherals.SchDoc, Regulators.SchDoc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]
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2017-01-16 Duplicating auto generated Digikey BOM in prep for manual edit
    [Digikey Order (CSV for Digikey)-Manual.csv]
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2017-03-11 Imported Taiyo Yuden footprints to PcbLib1
    Added NR6028T2R2N and NRS8040T150MJGJ
    [PcbLib1.PcbLib]
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2017-03-11 Removed a large quantity of diode bridges.
    No idea what that was all about.
    [SolarCharger.SchDoc]
2017-03-11 Updating solar charger circuit
    Also fixed trimpot symbol
    [Schlib1.SchLib, SolarCharger.SchDoc]
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2017-03-12 Miscellaneous cleanup and P/N fixing
    [Camera.SchDoc, MCU.SchDoc, Regulators.SchDoc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]
2017-03-12 Minor updates and value cleanup
    Also added optional tempco float voltage circuit
    [MCU.SchDoc, Peripherals.SchDoc, SolarCharger.SchDoc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]
2017-03-12 Fixing an Altium Stupid™
    Altium decided (between December and now, no version change) that busses
    require a corresponding net label, and the resulting error was nearly
    impossible to debug. If not for a Chinese blog post translated by Google
    Chrome into a horrid mess of "English", I wouldn't have been able to
    compile. Ever.
    [Peripherals.SchDoc, SDRAM.SchDoc, Solens.SchDoc]
2017-03-12 The beginning of The Great Respin
    Mostly ripup and footprint updates, +all PDF updates
    [PcbLib1.PcbLib, SolarCharger.SchDoc, Solens.PcbDoc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]
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2017-03-13 Mostly done with power section layout and routing
    [PcbLib1.PcbLib, Regulators.SchDoc, Solens.PcbDoc]
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2017-03-16 Ripping up UART2, prep for UART switch back to UART0
    [Solens.PcbDoc, WiFi.SchDoc]
2017-03-16 Reconnecting UART0 to MCU per Ben re: firmware switch
    [Solens.PcbDoc, WiFi.SchDoc]
2017-03-17 WiFi routing cleanup, post UART swap
    Also updating changelog and PDFs
    [Solens.PcbDoc]
2017-03-17 Miscellaneous ripup and layout
    Preparing for horizontal resizing, cleaning up some camera traces and
    ripping up non-critical sections
    [Solens.PcbDoc]
2017-03-17 Horizontal reduction, and more ripup
    Moved camera and WiFi west to clean up wasted space, ripping up
    non-critical MCU things in prep for vertical squishing
    [Solens.PcbDoc]
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2017-03-17 MCU and SDRAM layout and routing
    Moved SDRAM closer to MCU, pushed passives closer to MCU, removed some
    solder jumpers
    [MCU.SchDoc, PcbLib1.PcbLib, Solens.PcbDoc]
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2017-03-18 WiFi refactoring and programming header PNR
    Moving WiFi bulk decoupling closer to supply pad, JTAG jumpers to
    bottom, place and route for JTAG/SWD header
    [PcbLib1.PcbLib, Solens.PcbDoc, WiFi.SchDoc]
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2017-03-18 Miscellaneous PnR
    Placing DEBUG UART, I2C testpoints, RTC, etc
    [MCU.SchDoc, PcbLib1.PcbLib, SolarCharger.SchDoc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]
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2017-03-18 Updating board outline, chamfering corners
    Modified mounting hole footprints to coexist with chamfered corners,
    further reducing vertical board dimension
    [PcbLib1.PcbLib, Solens.PcbDoc, Solens.SchDoc]
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2017-03-19 Much more routing
    Improving SDRAM decoupling, misc. routing cleanup
    [Solens.PcbDoc]
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2017-03-24 Fixing DRC issues per JL and DRC reports, updating PDFs
    [PcbLib1.PcbLib, Solens.PcbDoc]
2017-03-27 Adding two GPIO lines between MCU and WiFi
    [MCU.SchDoc, Solens.SchDoc, WiFi.SchDoc]
2017-03-27 Routing MCU-WiFI GPIO, and silk additions/cleanup
    Also fixed errant trance in OV5642 footprint
    [PcbLib1.PcbLib, Solens.PcbDoc]
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2017-03-28 Generating Gerbers in preparation for Solens rev. B
    Using same Gerber job file as rev. A
    [Solens.DRL, Solens.GBL, Solens.GBO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]
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2017-03-30 Tweaking text to fix online DFM complaints
    [Solens.PcbDoc]
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2017-04-06 Fixing up for Digikey order
    [Digikey-BOM-order.csv, Digikey-OffBOM-order.csv]
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2017-04-19 Macrofab output job didn't get added to project
    [Solens.PrjPCB]
2017-04-19 Fixing part parameters
    [Camera.SchDoc, MCU.SchDoc, Peripherals.SchDoc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]
2017-04-20 More parameter fixing
    [Camera.SchDoc, MCU.SchDoc, Peripherals.SchDoc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]
2017-04-21 Comment coherency
    All comment fields have "necessary" information. Maybe one day I'll
    figure out this ODB export stuff...
    [Camera.SchDoc, MCU.SchDoc, Peripherals.SchDoc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]
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
